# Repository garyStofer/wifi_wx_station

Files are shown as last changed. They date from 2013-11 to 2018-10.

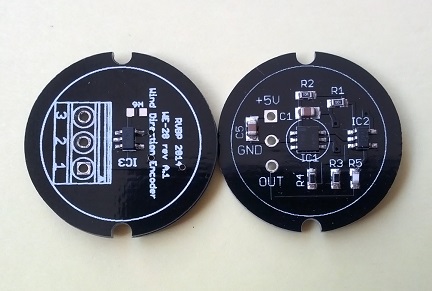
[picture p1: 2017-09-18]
Hardware/Wifi_WX_Station/Documents/WE28_PCB_small.jpg

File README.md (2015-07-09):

# wifi_wx_station
This project is for a full featured, self contained weather station that connects via WiFi to home network and uploads periodic readings
to various cloud based weather data ingestion service, such as Weather Underground, CWOP, WOW, etc.

The hardware is based on a Microchip controller with an attached Microchip WiFi module. 
The various sensors arepart of the project with the air data sensors (baro/temp/hyg) based onn i2C devices. 
The wind sensord are of unique solid state design ( optical, magnetic) and proide a high degree of precision, fidelity and reliability.

More information at http://wws.us.to

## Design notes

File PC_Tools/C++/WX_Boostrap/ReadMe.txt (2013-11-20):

Extract the files in this zip file to a location on your harddrive and make a shortcut to WX_Bootstrat.exe 
that you can put on the desktop for eaxmple.

The file TCPIP_Discovery.jar is a java program that displays the Netbioas name and the IP address of a WX_station
board after it's connected to the network. The Java Run time must be installed on the computer to run it.

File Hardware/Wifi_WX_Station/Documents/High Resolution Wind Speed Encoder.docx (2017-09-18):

# High Resolution Wind Speed Encoder

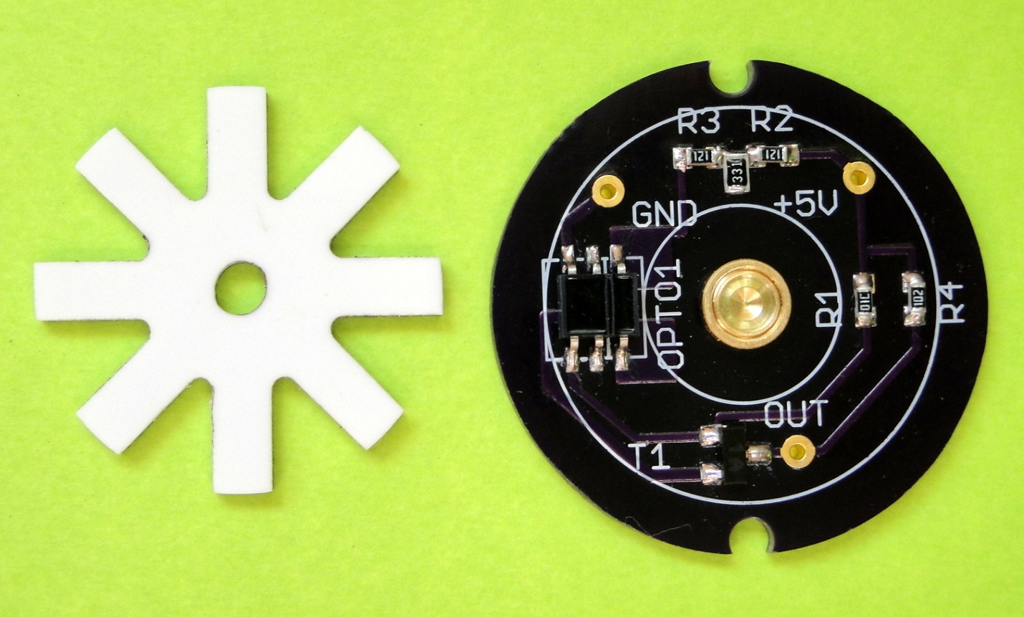
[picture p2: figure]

# Description

Based on a reflective optical interrupt device the sensors provides an eight fold increase in resolution for wind speed measurements compared to a basic reed switch device. This allows for a reduced measure interval, thus enabling the capture of short period wind gusts and airspeeds down to 0.5 Mph. The sensor asserts no drag on the anemometer cups, which, coupled with the sapphire bearing, makes for a virtually drag-free setup.

# Applications

- High definition/resolution wind speed monitoring & recording
- Capturing of micro gusts
- Capturing of very low wind-speeds
- DIY and custom weather stations

# Features

- Solid state
- Drag free
- Eight times the resolution compared to standard sensors
- Interfaces direct to microcontroller inputs
- No false readings due to reed switch bounce or magnetic fatigue
- Built in Hysteresis

# Electrical specifications

- Input voltage nominal 5V, maximum 5.5V
- Do not short output to ground
- Do not short output to +5V
- Required measure input impedance > 1K
- Current consumption 20 to 27mA @5V

Name | Symbol on PCB | Description | Condition
Ground | GND | Ground reference | --
Power | +5V | Regulated power input | 5V +/- 5% , less than 50mv noise
Output Signal | OUT | 8 pulses per revolution | Low <0.15V, | High <3.5>3V

# The device can sink and source 1.5ma. It is intended to be connected to a high impedance micro processor input through a series resistor and transorb or shottky diode for transient protection of the input on long cable runs.

# Mechanical specifications

- PCB dimension: Rround, 1” diameter
- Sensor to rotor distance 1.5mm +/- 10%

+5V regulated supply

System Ground

Output Signal

Note on revolution to wind speed calculations

When used with Inspeeds anemometer cups, 60 revolutions per minute equals 2.5MPH

When used with Davis Instruments cups , 60 RPM equals 2.25 MPH

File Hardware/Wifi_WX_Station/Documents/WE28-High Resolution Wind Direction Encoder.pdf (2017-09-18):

# High Resolution Wind Direction Encoder

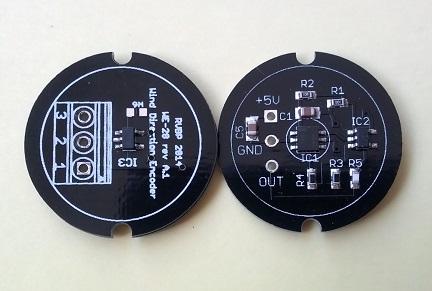
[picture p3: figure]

### Description

Based on a quad Hall- effect sensor the device reads the direction of a magnetic field provided by a small diametrically polarized magnet rotating above it. The device provides a linear voltage between 0 and 3V or 4.8V, coinciding with the absolute angle of the magnet and has no dead spot in the full 360 degree swing. The sensor, being completely solid state asserts no drag on the vane and has no mechanical parts to wear out.

### Applications

High definition/resolution wind direction monitoring & recording DIY and custom weather stations

### Features

Drag free
Maintenance free, solid state
No blind spots in full circle
No false readings due to partially worn potentiometer.

Interfaces direct to microcontroller ADC inputs

### Electrical specifications

Input voltage nominal 5V, maximum 5.5V Desired ADC input impedance > 100K DC output impedance ~ 10K
Current consumption 18 mA @5V Resolution +/- 0.5 deg

### Connections

Name | Symbol on PCB | Description | Condition
Ground | GND | Ground reference | --
Power | +5V | Regulated power input | 5V +/- 5% , less than 50mv noise
Output Signal | OUT | ~0V to ~3.3V coinciding with angle 0-360 degree | Low <0.1V, | High <3.3>3V

### Mechanical specifications

PCB dimension: Rround, 1” diameter Sensor to magnet distance 1.5mm +/- 10%

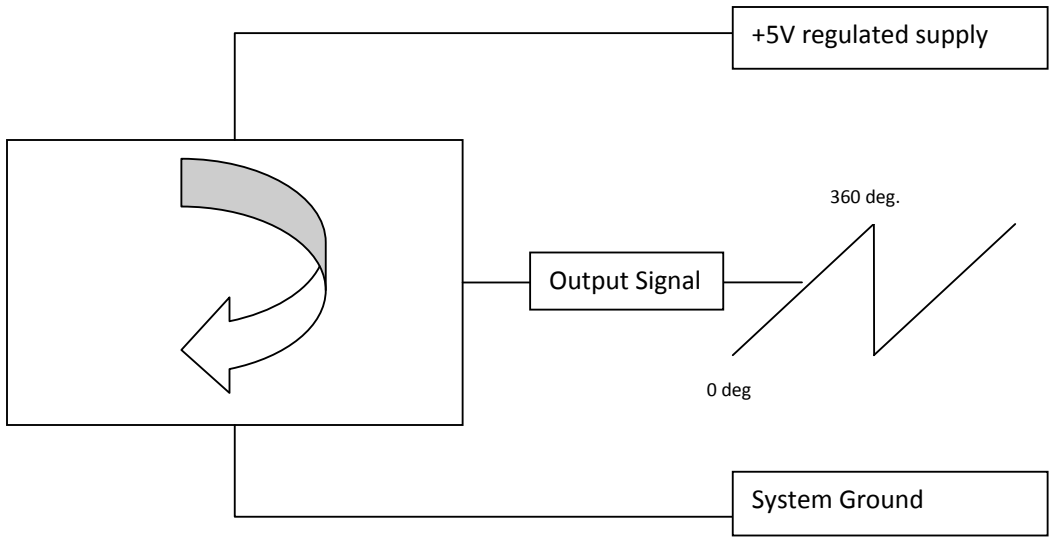
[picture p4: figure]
+5V regulated supply; System Ground; Output Signal; 0 deg; 360 deg.

See schematic for 3V v.s. 4.8V output build options.

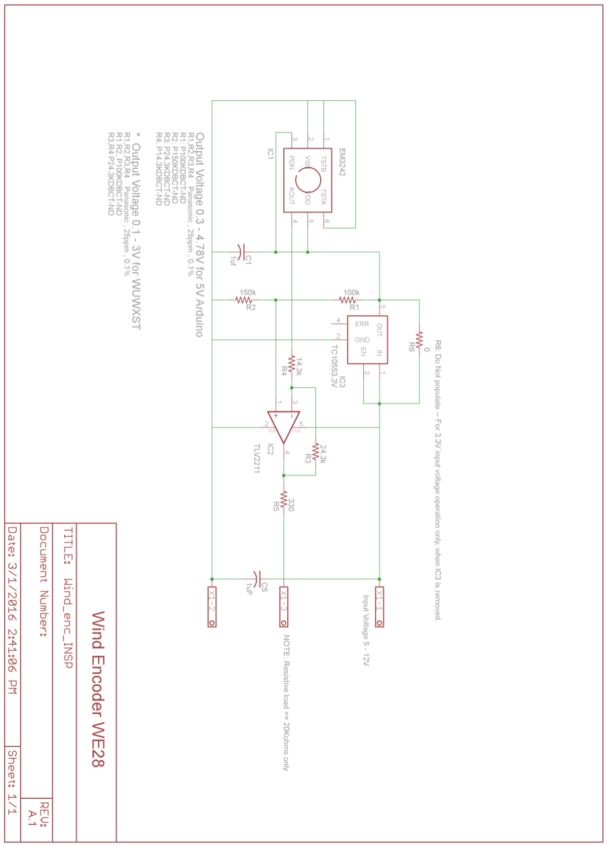
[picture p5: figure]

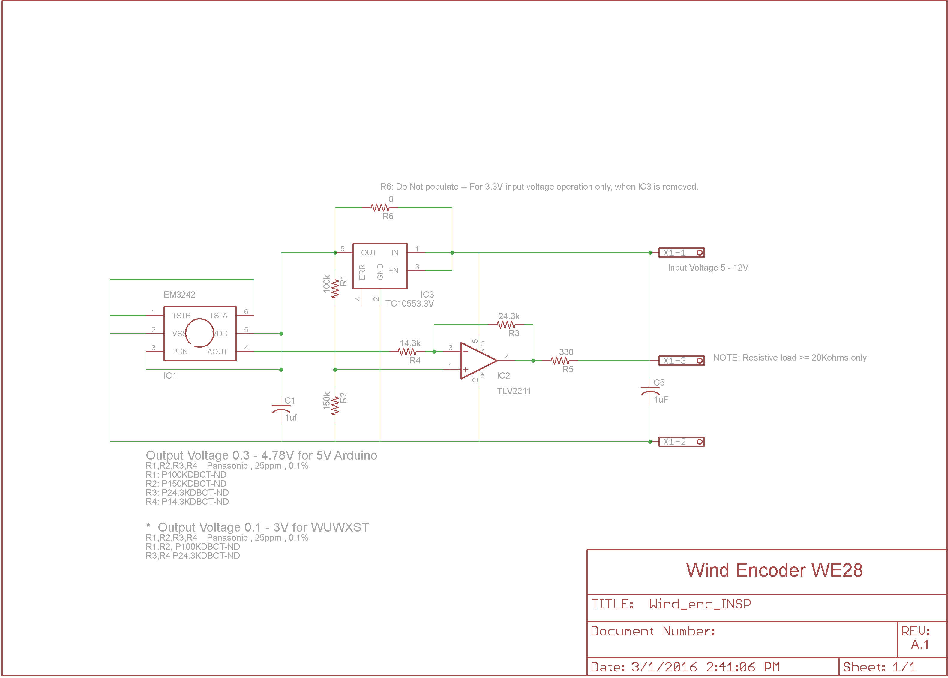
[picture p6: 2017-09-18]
Hardware/Wifi_WX_Station/WindDir_WE28_A.1/WE28_A1.png

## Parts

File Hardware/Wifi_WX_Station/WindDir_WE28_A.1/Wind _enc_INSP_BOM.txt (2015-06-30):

BOM for WE28-A1

OP-Amp 	TLV2211		DigiKey 	296-10501-1-ND	 
Encoder EM3242		Digikey  	974-1044-1-ND	 
VR 	TC10553.3V	DigiKey		TC10553.3VCT713CT-ND			 
R1 	100K 0.5% 25ppm 	 
R2	150K 0.1% 25ppm	 
R3	24.3k 0.1% 25ppm	 
R4 	14.3k 0.5% 25ppm	 
R5	330O 2%			 
C1,C2	1 uf/ 16V  			311-1457-1-ND

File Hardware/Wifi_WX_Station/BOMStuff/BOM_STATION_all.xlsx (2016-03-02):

Station Base Board PCB
Qty | Description | Value | Package | Parts | PN_ DigiKey | PN Mouser | Alt Vendor | Alt Vendor PN | Alt vendor Price | X10 | X100 | extended cost per one | extened +taxes
13 | Capacitor | 0.1uF | C0805 | C2, C3,C4,C5,C6,C8,C11,C13,C16,C18,C19,C20,C21 | 478-1395-1-ND | 80-C0805C104K5R |  |  |  | $0.48 | $2.30 | $0.62
1 | Capacitor, Polarized | 220uF/6V | SMC_D | C7 |  | 581-TPSC227K006Y0125 |  |  |  | $10.80 | $82.00 | $1.08
2 | Capacitor, Polarized | 22uF/10V | SMC_B | C1,C12 | 493-2357-1-ND | 74-TP3B226M010C1900A |  |  |  | $3.10 | $14.00 | $0.62
2 | Capacitor | 2.2uF | C0805 | C9, C10 | 445-3459-1-ND | 963-TMK212B7225KG-TR |  |  |  | $1.81 | $8.30 | $0.36
2 | Capacitor | 22p | C0603 | C14, C15 | 445-1273-1-ND | 77-VJ0603A220JXACBC (http://www.mouser.com/ProductDetail/Vishay-Vitramon/VJ0603A220JXACW1BC/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) |  |  |  | $0.30 |  | $0.06
1 | Resistor | 14K | R0603 | R8 | 311-14.0KHRCT-ND |  |  |  |  | $0.14 | $0.63 | $0.01
3 | Resistor | 100K | R0603 | R7,R19,R20 |  | 660-RK73H1JTTD1003F |  |  |  | $0.14 | $0.70 | $0.04
2 | Resistor | 1K | R0603 | R16, R17 | 311-1.0KGRCT-ND | 667-ERJ-3EKF1001V |  |  |  | $0.10 | $0.48 | $0.02
3 | Resistor | 10K | R0603 | R3,R4,R11, | 311-10.0KHRCT-ND | 667-ERJ-3EKF1002V |  |  |  | $0.14 | $0.63 | $0.04
2 | Resistor | 120o | R0603 | R1, R2, | 311-120GRCT-ND |  |  |  |  | $0.10 | $0.48 | $0.02
1 | Resistor | 8.2K | R0603 | R5 | 311-8.2KGRDKR-ND |  |  |  |  | $0.10 | $0.48 | $0.01
5 | Resistor | 4.7K | R0603 | R12,R14,R15,R23,R24 | 311-4.7KGRDKR-ND |  |  |  |  | $0.10 | $0.48 | $0.05
1 | Resistor | 470O | R0603 | R18 | 311-470GRCT-ND |  |  |  |  | $0.10 | $0.48 | $0.01
1 | Resistor | 2.2K | R0603 | R13 | 311-2.2KGRDKR-ND |  |  |  |  | $0.10 |  | $0.01
4 | Resistor | 26.1K | R0603 | R9,R10,R21,R22 | 311-26.1KHRCT-ND |  |  |  |  | $0.14 | $0.63 | $0.06
1 | VOLTAGE REGULATOR, LDO 3.3v | LD29150DT33R | DPACK | IC1 | 497-1496-1-ND | 511-LD29150DT33R |  |  |  | $9.50 | $82.00 | $0.95
1 | CRYSTAL | 32Khz | SMD-Can | Q1 | 300-8340-1-ND | 959-WX26-32.768K |  |  |  | $4.80 | $32.00 | $0.48
1 | Schottky Diode | B140 | SMB | D1 | 641-1111-1-ND | 625-SS14-E3 |  |  |  | $1.00 | $6.10 | $0.10
1 | Shottky Diode | MBR0520 | SOD123 | D2 | MBR0520TPMSCT-ND |  |  |  |  | $3.00 |  | $0.30
1 | MINI USB-B Conector | MINI-USB-32005-301 | 32005-301 | USB | ED2992CT-ND | 649-10033526-N3212LF |  |  |  | $4.83 | $42.20 | $0.48
1 | USB /UART | CP2104-GM | QFN24_4X4 | U1 | 336-2008-5-ND | 634-CP2104-F03-GM |  |  |  | $14.30 | $133.00 | $1.43
2 | Molex KK 6373 header with lock | CONN HEADER 3POS .100 VERT TIN | 0.1x3 Vert | FAN, SUN,+5V | WM4201-ND | 538-22-23-2031 |  |  |  | $1.53 | $12.20 | $0.31
0 | Male header 1x3 | 2 Not Loaded | 0.1x3 | UART1, I2C1 | 609-3464-ND |  |  |  |  | $1.46 |  | $0.00
0 | Male header 1x6 | 1 Not Loaded | 0.1x6 | JPROG | 609-3256-ND |  |  |  |  | $3.05 |  | $0.00
0 | Male header 1x10 | 3 Not Loaded | 0.1x10 | SV1,SV2,SV3 | 609-3279-ND |  |  |  |  | $4.61 |  | $0.00
0 | Male header 1x5 | 1 Not Loaded | 0.1x5 | ANA | 609-3462-ND |  |  |  |  | $1.92 |  | $0.00
1 | RJ45 Jack LP-Vertical Molex | RJ45-8VERT | RJ45_VERT | J1 | AE10396-ND | 538-42878-1001 |  |  |  | $6.70 | $64.70 | $0.67
1 | RJ11 Jack LP-Vertical Molex | RJ11-6VERT | RJ11-6VERT | J5 /BaroHyg |  | 538-42878-6264 |  |  |  | $9.90 | $73.70 | $0.99
1 | PIC MCU 128K | PIC24FJ128GA008 | TQFP80-12X12 | U3 | PIC24FJ128GA008-I/PT-ND5.2 | 579-24FJ128GA008IPT |  |  |  | $37.00 | $307.00 | $3.70
0 | PIC MCU 256K/ Alternate | PIC24FJ256GA108 | TQFP80-12X12 |  | PIC24FJ256GA108-I/PT-ND7.42 |  |  |  |  | $51.80 |  | $0.00
1 | EEprom 512kbit | 25LC512 | SOIC8 | U2 | 25LC512-I/SN-ND | 579-25LC512-I/SN |  |  |  | $17.00 | $157.00 | $1.70
3 | Tactile Switch | SWITCH-MOMENTARY-2SMD |  | S1, S2, Reset | P12955SCT-ND | 667-EVQ-Q2P03W |  |  |  | $2.73 | $20.40 | $0.82
1 | LED | ambr | CHIP-LED0603 | L2 | 475-2558-1-ND | 859-LTST-C190KFKT |  |  |  | $0.78 |  | $0.08
1 | LED | grn | CHIP-LED0603 | L1 | 475-1409-1-ND | 859-LTST-C190KGKT |  |  |  | $0.74 |  | $0.07
1 | LED | red | CHIP-LED0603 | L3 | 475-2512-1-ND | 859-LTST-C190KRKT |  |  |  | $0.78 |  | $0.08
1 | PCB, Elcrow |  |  |  |  | Elcrow 10 PCB order 5x10 |  |  |  | $20.00 |  | $2.00
 |  |  |  |  |  |  |  |  |  |  |  | $17.18 | $18.72
WiFi Interface Module & PCB
Qty | Description | Value | Package | Parts
2 | Capacitor | 0.1uF | C0805 | C1, C2 | 478-1395-1-ND |  |  |  |  | $0.48 | $2.20 | $0.10
1 | Resistor | 10K | R0603 | R2 | 311-10.0KHRCT-ND |  |  |  |  | $0.10 | $0.48 | $0.01
1 | Resistor | 4.7K | R0603 | R1 | 311-4.70KHRCT-ND |  |  |  |  | $0.10 | $0.48 | $0.01
1 | Capacitor Polarized | 4.7uF | R/2012-12R | C3 | 399-3696-1-ND | 80-T491A475K010 |  |  |  | $2.95 | $25.50 | $0.30
1 | Male Header 2x5 | M05X2 | 2X5-RA-HEADER | JP1 | 609-3410-ND |  |  |  |  | $3.56 |  | $0.36
1 | Mirochip/ZeroG Wifi module | MRF24WG0MA | MRF24WG | M1 | MRF24WG0MB/RM-ND | digitalrepair@hotmail.com<digitalrepair@hotmail.com>; | e-bay |  | $10.00 | $210.00 |  | $21.00
1 | PCB. Elcrow |  |  |  |  | Elcrow 10 PCB order 5x5 |  |  |  | $16.00 |  | $1.60
 |  |  |  |  |  |  |  |  |  |  |  | $23.37 | $25.47
Power feed & Sun, Rain input PCB
Qty | Description | Value | Package | Parts
2 | Molex KK 6373 header with lock | CONN HEADER 3POS .100 VERT TIN |  | Rain, Sun | WM4201-ND |  |  |  |  | $2.80 |  | $0.56
1 | MINI USB-B Conector | MINI-USB-32005-301 | 32005-301 | USB | ED2992CT-ND | 649-10033526-N3212LF |  |  |  | $4.83 |  | $0.48
2 | RJ45 Jack | RJ45-8VERT | RJ45_VERT | J1, J2 | AE10396-ND | 538-42878-1001 |  |  |  | $6.67 |  | $1.33
1 | PCB, ELCROW |  |  |  |  | Elcrow 10 PCB order 5x5 |  |  |  | $16.00 |  | $1.60
 |  |  |  |  |  |  |  |  |  |  |  | $3.98 | $4.33
Wind tree distributor PCB
Qty | Description | Value | Package | Parts
1 | RJ45 Jack | RJ45-8VERT | RJ45_VERT | J1 | AE10396-ND | 538-42410-8314 |  |  |  | $7.47 |  | $0.75
1 | PCB. ELcrow | Gold Phoenix 100 @ $1.10 |  |  |  | Elcrow 10 PCB order 5x5 |  |  |  | $16.00 |  | $1.60
 |  |  |  |  |  |  |  |  |  |  |  | $2.35 | $2.56
Wind VANE
1 | Wind vane | DAVIS WIND VANE 7904 |  | http://www.ambientweather.com/dain79wivafo.html |  |  |  |  |  | $150.00 |  | $15.00
1 | Magnet diametrically polarized |  |  |  |  |  |  |  |  | $5.00 |  | $0.50
2 | Bearings |  |  |  |  |  |  |  |  | $25.00 |  | $5.00
1 | Axcel |  |  |  |  |  |  |  |  | $40.00 |  | $4.00
2 | C-clips 1/4 |  |  |  |  |  |  |  |  | $10.00 |  | $2.00
1 | Ft Cable 3-pole |  |  |  |  |  |  |  |  | $50.00 |  | $5.00
1 | Housing |  |  |  |  |  |  |  |  | $75.00 | $400.00 | $7.50
 |  |  |  |  |  |  |  |  |  |  |  | $39.00 | $42.51
Wind Direction Sensor PCB & magnet
1 | IC | AS5030 | TSSOP 16 |  | AS5030-ATSTCT-ND | 985-AS5030-ATSU @4.86x10 | Future |  | $2.89 | $48.60 |  | $4.86
3 | Capacitor | 1uF | C0805K | C1, C2, C5 | 490-5320-1-ND |  |  |  |  | $3.05 |  | $0.91
1 | Pol Capacitor | 220uF/6.3V | SMC_D | C6 |  | 581-TPSC227K006Y0125 |  |  |  | $10.80 |  | $1.08
1 | Resistor | 8.2k | R0603 | R6 | 311-8.2KGRDKR-ND |  |  |  |  | $0.10 |  | $0.01
1 | Resistor | 26.2K | R0603 | R2 | 311-26.1KHRCT-ND |  |  |  |  | $0.10 |  | $0.01
1 | Diametrically magnetized magnet |  |  |  | K&J magnets |  |  |  |  | $5.00 |  | $0.50
1 | Resistor | 6.8K | R0603 | R1 | 311-6.80KHRCT-ND |  |  |  |  | $0.10 | $0.63 | $0.01
1 | PCB, Elcrow |  |  |  |  | Elcrow 10 PCB order 5x5 |  |  |  | $16.60 |  | $1.66
 |  |  |  |  |  |  |  |  |  |  |  | $9.04 | $9.86
Anemometer
1 | Anemometer | DAVIS VANTAGE VUE WIND CUPS 7342.178 |  | http://www.ambientweather.com/da7342178.html |  |  |  |  |  | $150.00 |  | $15.00
1 | Housing 2parts |  |  |  |  |  |  |  |  | $60.00 | $400.00 | $6.00
2 | Bearings |  |  |  |  |  |  |  |  | $25.00 |  | $5.00
1 | Axcel |  |  |  |  |  |  |  |  | $40.00 |  | $4.00
2 | C-clips 1/4 |  |  |  |  |  |  |  |  | $10.00 |  | $2.00
1 | Ft Cable 3-pole |  |  |  |  |  |  |  |  | $50.00 |  | $5.00
 |  |  |  |  |  |  |  |  |  |  |  | $37.00 | $40.33
Windspeed sensor PCB and Rotor
1 | Reflective opto interrupter | OSRAM SFH9201 |  | OPTO1 | 475-2658-1-ND | 720-SFH9206 |  |  |  | $7.42 | $67.20 | $0.74
1 | Transistor NPN | MMBT3904 |  | T1 | MMBT3904TPMSCT-ND |  |  |  |  | $2.07 |  | $0.21
2 | Resistor | 120 O | R0603 | R1,R2 | 311-120GRCT-ND | 71-CRCW0603-120-E3 |  |  |  | $0.10 | $0.48 | $0.02
1 | Resistor | 10K | R0603 | R3 | 311-10.0KHRCT-ND | 71-CRCW0603-10K-E3 |  |  |  | $0.14 | $0.63 | $0.01
1 | Resistor | 330 O | R0603 | R5 |  | 71-CRCW0603-330-E3 |  |  |  | $0.10 |  | $0.01
1 | Resistor | 1K | R0603 | R4 | 311-1.0KHRCT-ND | 71-CRCW0603-1.0K-E3 |  |  |  | $0.14 | $0.63 | $0.01
1 | PCB |  |  |  |  | Elcrow 10 PCB order 5x5 |  |  |  | $16.60 | $0.06 | $1.66
1 | Rotor |  |  |  |  |  |  |  |  | $40.00 |  | $4.00
 |  |  |  |  |  |  |  |  |  |  |  | $6.67 | $7.27
Barometer & HoneyWell Hygrometer PCB
Qty | Description |  | Package | Parts
2 | Resistor | 470O | R0603 | R1,R2 | 311-470GRCT-ND | 71-CRCW0603-470-E3 |  |  |  | $0.10 | $0.48 | $0.02
2 | Capacitor | 0.1uF | C0805 | C1, C4 | 478-1395-1-ND | 80-C0805C104K5R |  |  |  | $0.48 | $2.20 | $0.10
1 | Capacitor, Polarized | 22uF/10V | SMC_B | C3 | 493-2357-1-ND |  |  |  |  | $4.69 |  | $0.47
1 | Sensor Hygrometer | HIH_6131,hih7131 | SOIC-8 | U1 |  | 785-HIH-6131-021-001 |  |  |  | $149.10 |  | $14.91 |  | digikey hih7131 : $15.67 | allied hih6131 $13.50
1 | Sensor Barometer /Temperatur | BMP085 | LCC8 | U2 | 828-1005-1-ND |  | China |  | $2.50 | $60.52 |  | $6.05
1 | RJ12 LP horizontal | RJ12-6pole Hor |  |  |  | 538-43249-6101 |  |  |  | $10.10 |  | $1.01
1 | PCB |  |  |  |  | Elcrow 10 PCB order 5x5 |  |  |  | $16.60 |  | $1.66
 |  |  |  |  |  |  |  |  |  |  |  | $24.22 | $26.40
Barometer & Silabs Hygrometer PCB
Qty | Description |  | Package | Parts
2 | Resistor | 470O | R0603 | R1,R2 | 311-470GRCT-ND | 71-CRCW0603-470-E3 |  |  |  | $0.10 | $0.48 | $0.02
2 | Capacitor | 0.1uF | C0805 | C1, C4 | 478-1395-1-ND | 80-C0805C104K5R |  |  |  | $0.48 | $2.20 | $0.10
1 | Capacitor, Polarized | 22uF/10V | SMC_B | C3 | 493-2357-1-ND | 80-T491A226K019 |  |  |  | $4.69 |  | $0.47
1 | Sensor Barometer /Temperatur | BMP085 | LCC8 | U2 | 828-1005-1-ND |  | China |  | $2.50 | $60.52 |  | $6.05
1 | Si7021-A10-GM1 | Silabs 2% with filter |  |  |  | 634-SI7021-A-GM1 $4.27 |  |  |  | $42.70 | $395.00 | $4.27
1 | RJ12 LP horizontal | RJ12-6pole Hor |  |  |  | 538-43249-6101 |  |  |  | $10.10 |  | $1.01
1 | PCB |  |  |  |  | Elcrow 10 PCB order 5x5 |  |  |  | $16.00 |  | $1.60
 |  |  |  |  |  |  |  |  |  |  |  | $13.52 | $14.73
Solar Sensor
1 | Solar Cell | CPC1822 | SOIC-8 |  | CLA289-ND |  |  |  |  | $12.40 | $98.00 | $1.24
1 | OP-amp | MAX4330 | SOT23-5 |  | MAX4330EUK+TCT-ND |  |  |  |  | $32.20 | $213.00 | $3.22
2 | Capacitor | 0.1uF | C0805 | C1, C2 | 478-1395-1-ND |  |  |  |  | $0.48 | $2.20 | $0.10
1 | Resistor | 47K |  | R1 | 311-47.0KHRCT-ND |  |  |  |  | $0.14 | $0.63 | $0.01
1 | Molex KK series connector housing | CONN HOUS 3POS .100 W/RAMP/RIB |  |  | WM2003-ND |  |  |  |  | $1.74 | $10.73 | $0.17
3 | Crimp terminal for Molex KK connector |  |  |  | WM1114CT-ND | 538-08-50-0114 |  |  |  | $0.50 | $4.66 | $0.15
1 | PCB | Gold Phoenix 100 @ $1.10 |  |  |  |  |  |  |  | $10.00 |  | $1.00
 |  |  |  |  |  |  |  |  |  |  |  | $5.89 | $6.42
Baro_hyg_temp Cable
2 | RJ12 / Cat3 modular Plugs |  |  |  |  | 154-7623-6 |  |  |  | $2.40 | $18.00 | $0.48
1 | RJ12 6 pole cable |  |  |  |  |  |  |  |  | $10.00 |  | $1.00
 |  |  |  |  |  |  |  |  |  |  |  | $1.48 | $1.61
Post Enclosure , cabling, power supply
1 | Severe Weather Post SLV COMP | Item # 160835 |  |  | Lowes |  |  |  |  | $100.00 |  | $10.00
1 | Severe Weather Kove Base | Item #7067 |  |  | Lowes |  |  |  |  | $70.00 |  | $7.00
1 | Severe Weather Post Cap Bevel | Item #100437 |  |  | Lowes |  |  |  |  | $50.00 |  | $5.00
1 | FAN 12V/5V | FAN 12V/5V, 92mmx92mm |  |  | 259-1468-ND |  |  |  |  | $24.64 |  | $2.46
2 | Crimp terminal for Molex KK connector |  |  |  | WM1114CT-ND |  |  |  |  | $0.50 |  | $0.10
1 | Molex KK series connector housing | CONN HOUS 3POS .100 W/RAMP/RIB |  |  | WM2001-ND |  |  |  |  | $1.74 |  | $0.17
2 | Mounting bracket for base pcb |  |  |  |  |  |  |  |  | $10.00 |  | $2.00
1 | USB Powersupply 5V/1A USB-Mini-B |  |  |  |  |  |  |  |  | $50.00 |  | $5.00
1 | 25 feet CAT5 Ethernet cable 22ga |  |  |  | Frys |  |  |  |  | $120.00 |  | $12.00
1 | 14 feet CAT5 Ethernet cable 22ga |  |  |  | Frys |  |  |  |  | $50.00 |  | $5.00
 |  |  |  |  |  |  |  |  |  |  |  | $0.00
No labor | Cost for main brd, Wifi, & baro_hyg sensor SI | $60.54 | +plus $14 for HWELL hyg |  | No labor, calculated from X10 order quantities |  | Parts Shipping cost + $2
No labor | Cost for Winspeed sensor board & Rotor | $7.27 |  |  | "
No labor | cost for Wind Direction sensord board & Magnet | $9.86 |  |  | "

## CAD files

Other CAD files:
Hardware/Wifi_WX_Station/Mechanical_CAD/PCB bracket.skp
Hardware/Wifi_WX_Station/Mechanical_CAD/WindSpeed2Housing top.skp
Hardware/Wifi_WX_Station/Mechanical_CAD/WindSpeedHousing2_bottom.skp
Hardware/Wifi_WX_Station/Mechanical_CAD/Wind_Speed_Axel.skp
Hardware/Wifi_WX_Station/Mechanical_CAD/Wind_Vane_Axel.skp
Hardware/Wifi_WX_Station/Mechanical_CAD/Wind_speed_rotor.skp
Hardware/Wifi_WX_Station/Mechanical_CAD/Wind_speed_rotor_cnc.skp

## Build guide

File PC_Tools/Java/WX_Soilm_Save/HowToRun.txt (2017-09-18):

First Install Java Runtime environment (JRE) on the computer. If it's a Windows XP computer you will get 
an notice that Java 8 is not actively supported any more. You can disregard the message and install it anyway. 

The application is WXSoilSave.jar and requires two command line arguments, one for the IP address the other
for the sample interval (optional, default 12 mins).

java -jar WXSoilSave.jar -ip 192.168.1.201 -i 12 

	Mandatory argument "-ip  xxx.xxx.xxx.xxx" defines the address of the WX station 
	Optional argument "-i nn" sets the interval in minutes for polling of that station.

The file "run.cmd" is a batch file that can be customized for your particular requirements. 
Make a copy each of this file and change the IP addresses to match the addresses from the stations
and run each copy.

The output data file will be stored in the local folder and named according to the IP address of the
station sampled. 

You can stop the program by switching to the terminal window and close it or issue a Ctrl-C.
The application also terminates if the station is off and it times-out on the read.

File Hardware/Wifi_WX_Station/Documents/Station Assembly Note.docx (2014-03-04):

## A few notes on assembly of the Weather Station

In random order:

Check out the Help and the Document section on http://WunderWeatherstation.wordpress.com for hookup and configuration procedures. You will have to download some PC tools to bootstrap the device onto your Wifi network.

The Air-Data sensor currently comes with a 2” ribbon cable and a 5 pin inline connector. If your installation requires a greater distance between the main PCB and the sensor you can extend the wire with a suitable cable up to 20 feet. The short connection is best used with a force aspirated enclosure where a fan constantly draws air through the enclosure. I will have a new version of sensor available soon which uses a modular connector and a FAX/Phone cable for more hookup options.

On the wind tree assembly it should be obvious how to put it together, but make sure that you glue the PVC parts together to make them water proof. Use a run of electrical tape to hold together and seal the joints between the black Inspeed housings and the white PVC parts .

For esthetics and protection from UV I usually paint the finished PVC parts .

If you don’t use the sun input on the round wind tree distribution pcb solder the holes shut.

The Distribution PCB in the bottom of the 1” coupling needs an O-ring to seal, make sure that when you glue this together that the PCB is held tight against the O-ring without it wiggling. You will need to hold the parts together for a minute or so while the glue sets.

Don’t glue the Wind tree to the 1” pipe, simply press on and use electrical tape to hold the joint together.

If you permanently mount the wind tree on a pipe longer than 3” drill one ½ hole near the top, so that air can circulate in the pipe to prevent condensation near the connector.

The calibration factor for the Inspeed anemometer cups is exactly 2.5. Make sure you re-enter this in the sensor configuration page after a reset. The Default 2.25 is for the Davis cups.

Use good CAT5 cable, soft and pliable. Outdoor quality is preferred. On the cheap stuff the outer shell can crack after only one year out in the sun. Then the rainwater can enter the cable and flood your base station PCB, and that’s ugly.

Make sure not to forget to set the station elevation in the Station Setup page even if you don’t report to weather underground. The elevation is needed to calculate the barometer reading. A reset is needed after the elevation has been changed.

Except for the solar sensor, the various gains and offsets should not need tweaking unless you have reliable data to justify it.

The solar sensor should be calibrated to read about 950 Watt/m2 facing directly at the sun. The current sensor while electrically linear is direction sensitive and needs some optical diffusion mechanism to be less affected by incidence angle.

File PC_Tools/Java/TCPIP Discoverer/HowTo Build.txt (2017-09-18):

This is a Java Netbeans project. 
Last built with NB 8.1 Using Java 6 source 

The executable .jar file is found in the dist folder.

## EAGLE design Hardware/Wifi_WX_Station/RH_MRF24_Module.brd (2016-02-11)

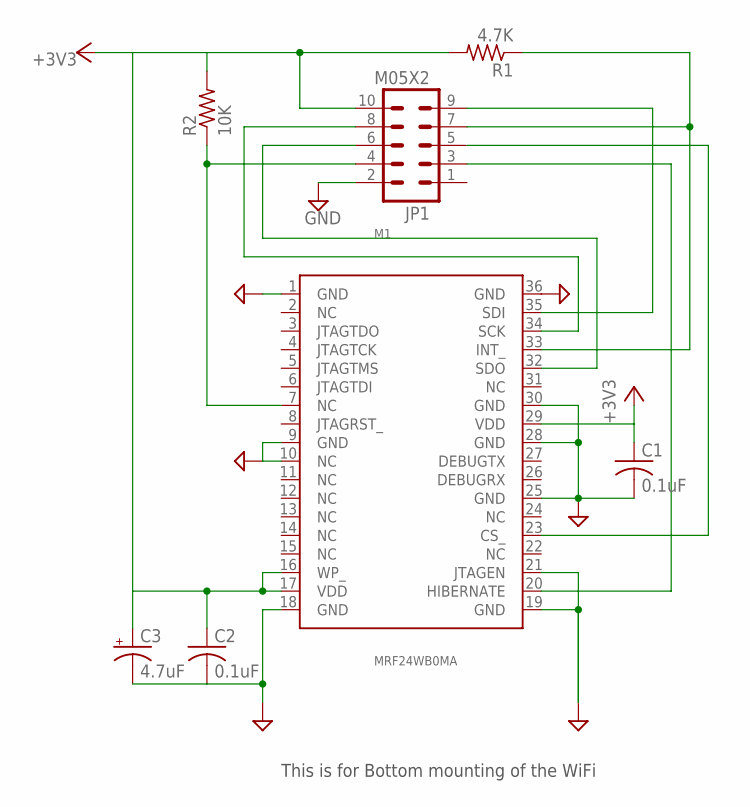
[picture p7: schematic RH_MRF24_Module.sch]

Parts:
C1, C2: 0.1uF; C0805
C3: 4.7uF; R/2012-12R
JP1: M05X2; 2X5-RA-HEADER
M1: MRF24WB0MA; MRF24W
R1: 4.7K; R0603
R2: 10K; R0603

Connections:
+3V3: C1.1, C2.1, C3.+, JP1.10, M1.16 (WP_), M1.17 (VDD), M1.29 (VDD), R1.2, R2.2
CS_: JP1.5, M1.23 (CS_)
GND: C1.2, C2.2, C3.-, JP1.2, M1.1 (GND), M1.9 (GND), M1.10 (NC), M1.18 (GND), M1.19 (GND), M1.21 (JTAGEN), M1.25 (GND), M1.28 (GND), M1.30 (GND), M1.36 (GND)
HIBER: JP1.3, M1.20 (HIBERNATE)
INT_: JP1.7, M1.33 (INT_), R1.1
RESET_: JP1.4, M1.7 (NC), R2.1
SCK: JP1.8, M1.34 (SCK)
SDI: JP1.9, M1.35 (SDI)
SDO: JP1.6, M1.32 (SDO)

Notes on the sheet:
This is for Bottom mounting of the WiFi

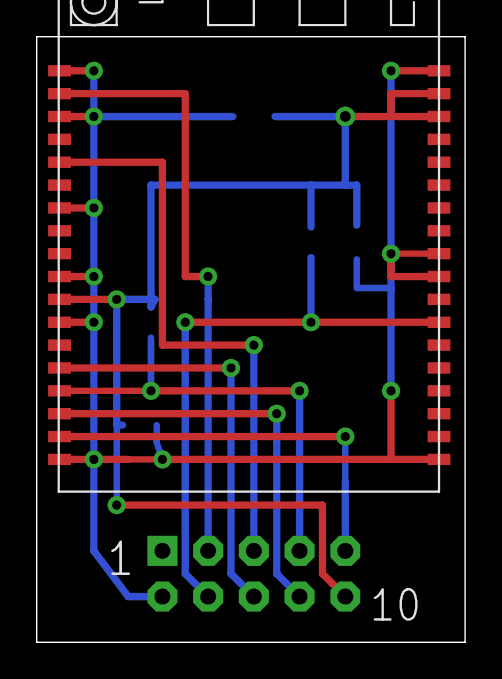
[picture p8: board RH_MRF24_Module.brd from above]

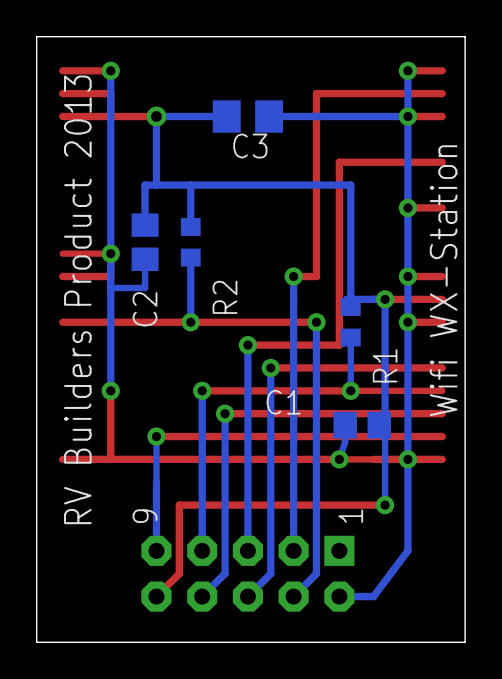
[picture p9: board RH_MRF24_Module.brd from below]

Board: 2 copper layers, 23.8 x 33.6 mm, 7 parts (6 on the bottom side), 9 nets.

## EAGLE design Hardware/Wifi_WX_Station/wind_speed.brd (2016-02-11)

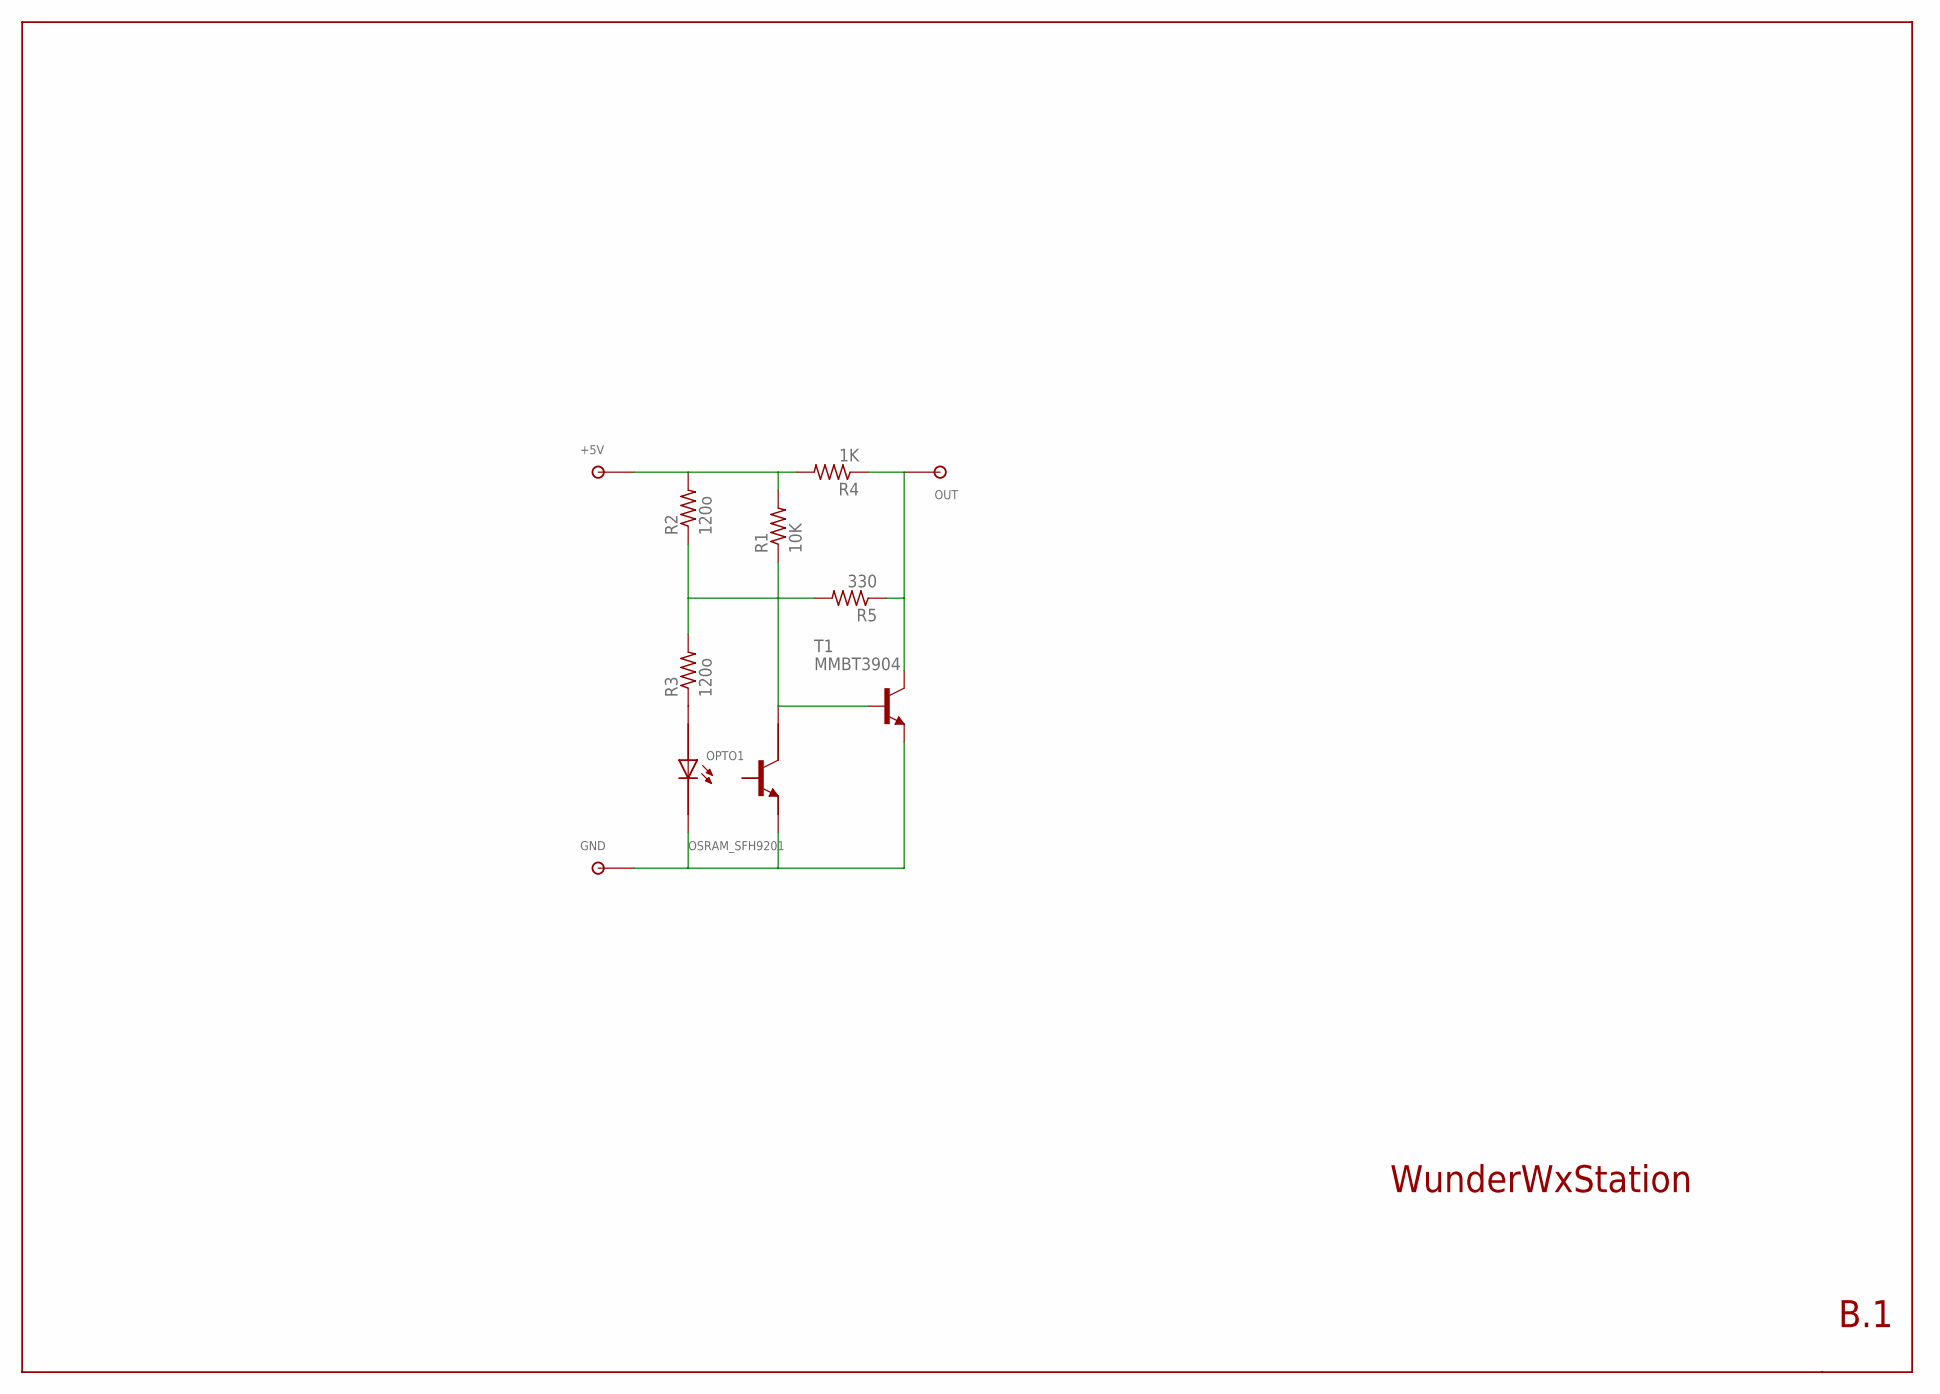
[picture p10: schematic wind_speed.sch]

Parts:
+5V: TPSOL; TP_SOL
GND: TPSOL; TP_SOL
OPTO1: OSRAM_SFH9201; OSRAM-6
OUT: TPSOL; TP_SOL
R1: 10K; R0603
R2, R3: 120o; R0603
R4: 1K; R0603
R5: 330; R0603
T1: MMBT3904; SOT23

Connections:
unnamed: OPTO1.P$4 (C), R1.1, T1.1 (B)
unnamed: GND.P$1, OPTO1.P$3 (E), OPTO1.P$6 (CATH), T1.2 (E)
unnamed: +5V.P$1, R1.2, R2.2, R4.2
unnamed: OUT.P$1, R4.1, R5.1, T1.3 (C)
unnamed: OPTO1.P$1 (AN), R3.1
unnamed: R2.1, R3.2, R5.2

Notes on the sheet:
WunderWxStation
B.1

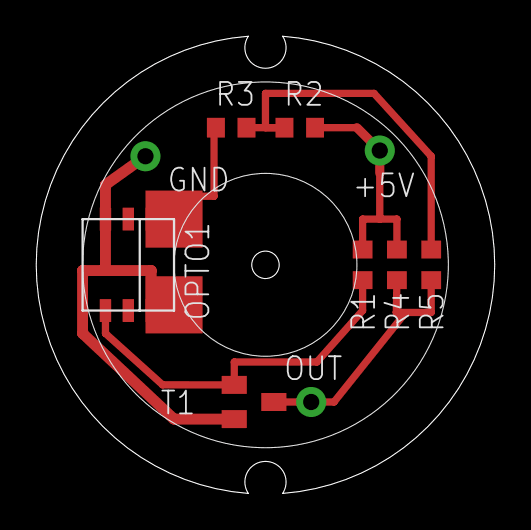
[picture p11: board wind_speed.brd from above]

Board: 2 copper layers, 25.5 x 25.4 mm, 10 parts (0 on the bottom side), 6 nets.

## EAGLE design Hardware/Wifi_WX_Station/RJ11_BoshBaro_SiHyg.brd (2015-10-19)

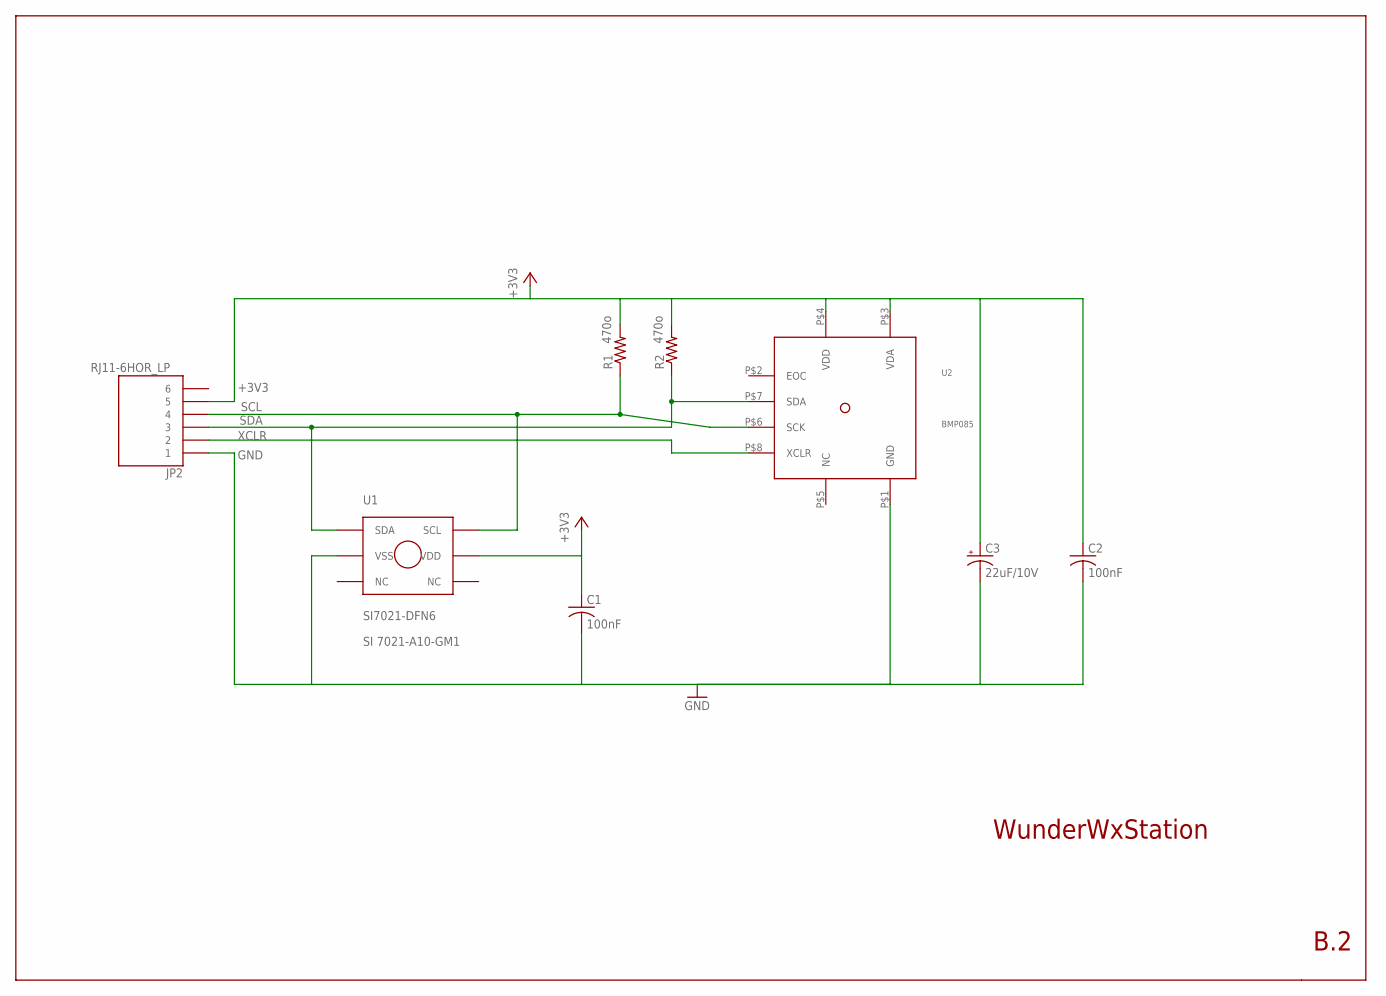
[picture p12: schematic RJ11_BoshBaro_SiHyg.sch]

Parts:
C1, C2: 100nF; C0805K
C3: 22uF/10V; SMC_B
JP2: RJ11-6HOR_LP; RJ11_HOR_LP
R1, R2: 470o; R0603
U1: SI7021-DFN6; DFN-6_SILABS
U2: BMP085; LCC8

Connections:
+3V3: C1.1, C2.1, C3.+, JP2.P$5 (5), R1.2, R2.2, U1.P$5 (VDD), U2.P$3 (VDA), U2.P$4 (VDD)
GND: C1.2, C2.2, C3.-, JP2.P$1 (1), U1.P$2 (VSS), U2.P$1 (GND)
SCL: JP2.P$4 (4), R1.1, U1.P$6 (SCL), U2.P$6 (SCK)
SDA: JP2.P$3 (3), R2.1, U1.P$1 (SDA), U2.P$7 (SDA)
XCLR: JP2.P$2 (2), U2.P$8 (XCLR)

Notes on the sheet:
WunderWxStation
B.2
SI 7021-A10-GM1

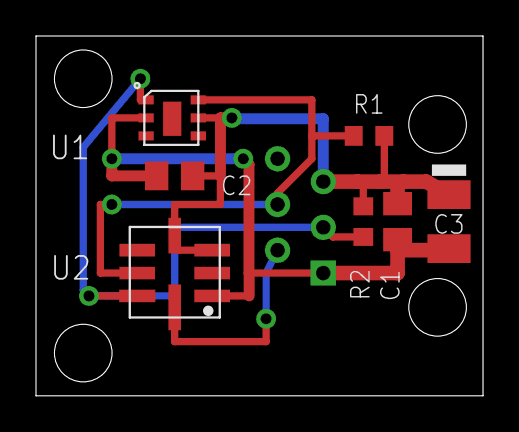
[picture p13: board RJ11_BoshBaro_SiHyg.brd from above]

Board: 2 copper layers, 24.8 x 20.0 mm, 8 parts (1 on the bottom side), 5 nets.

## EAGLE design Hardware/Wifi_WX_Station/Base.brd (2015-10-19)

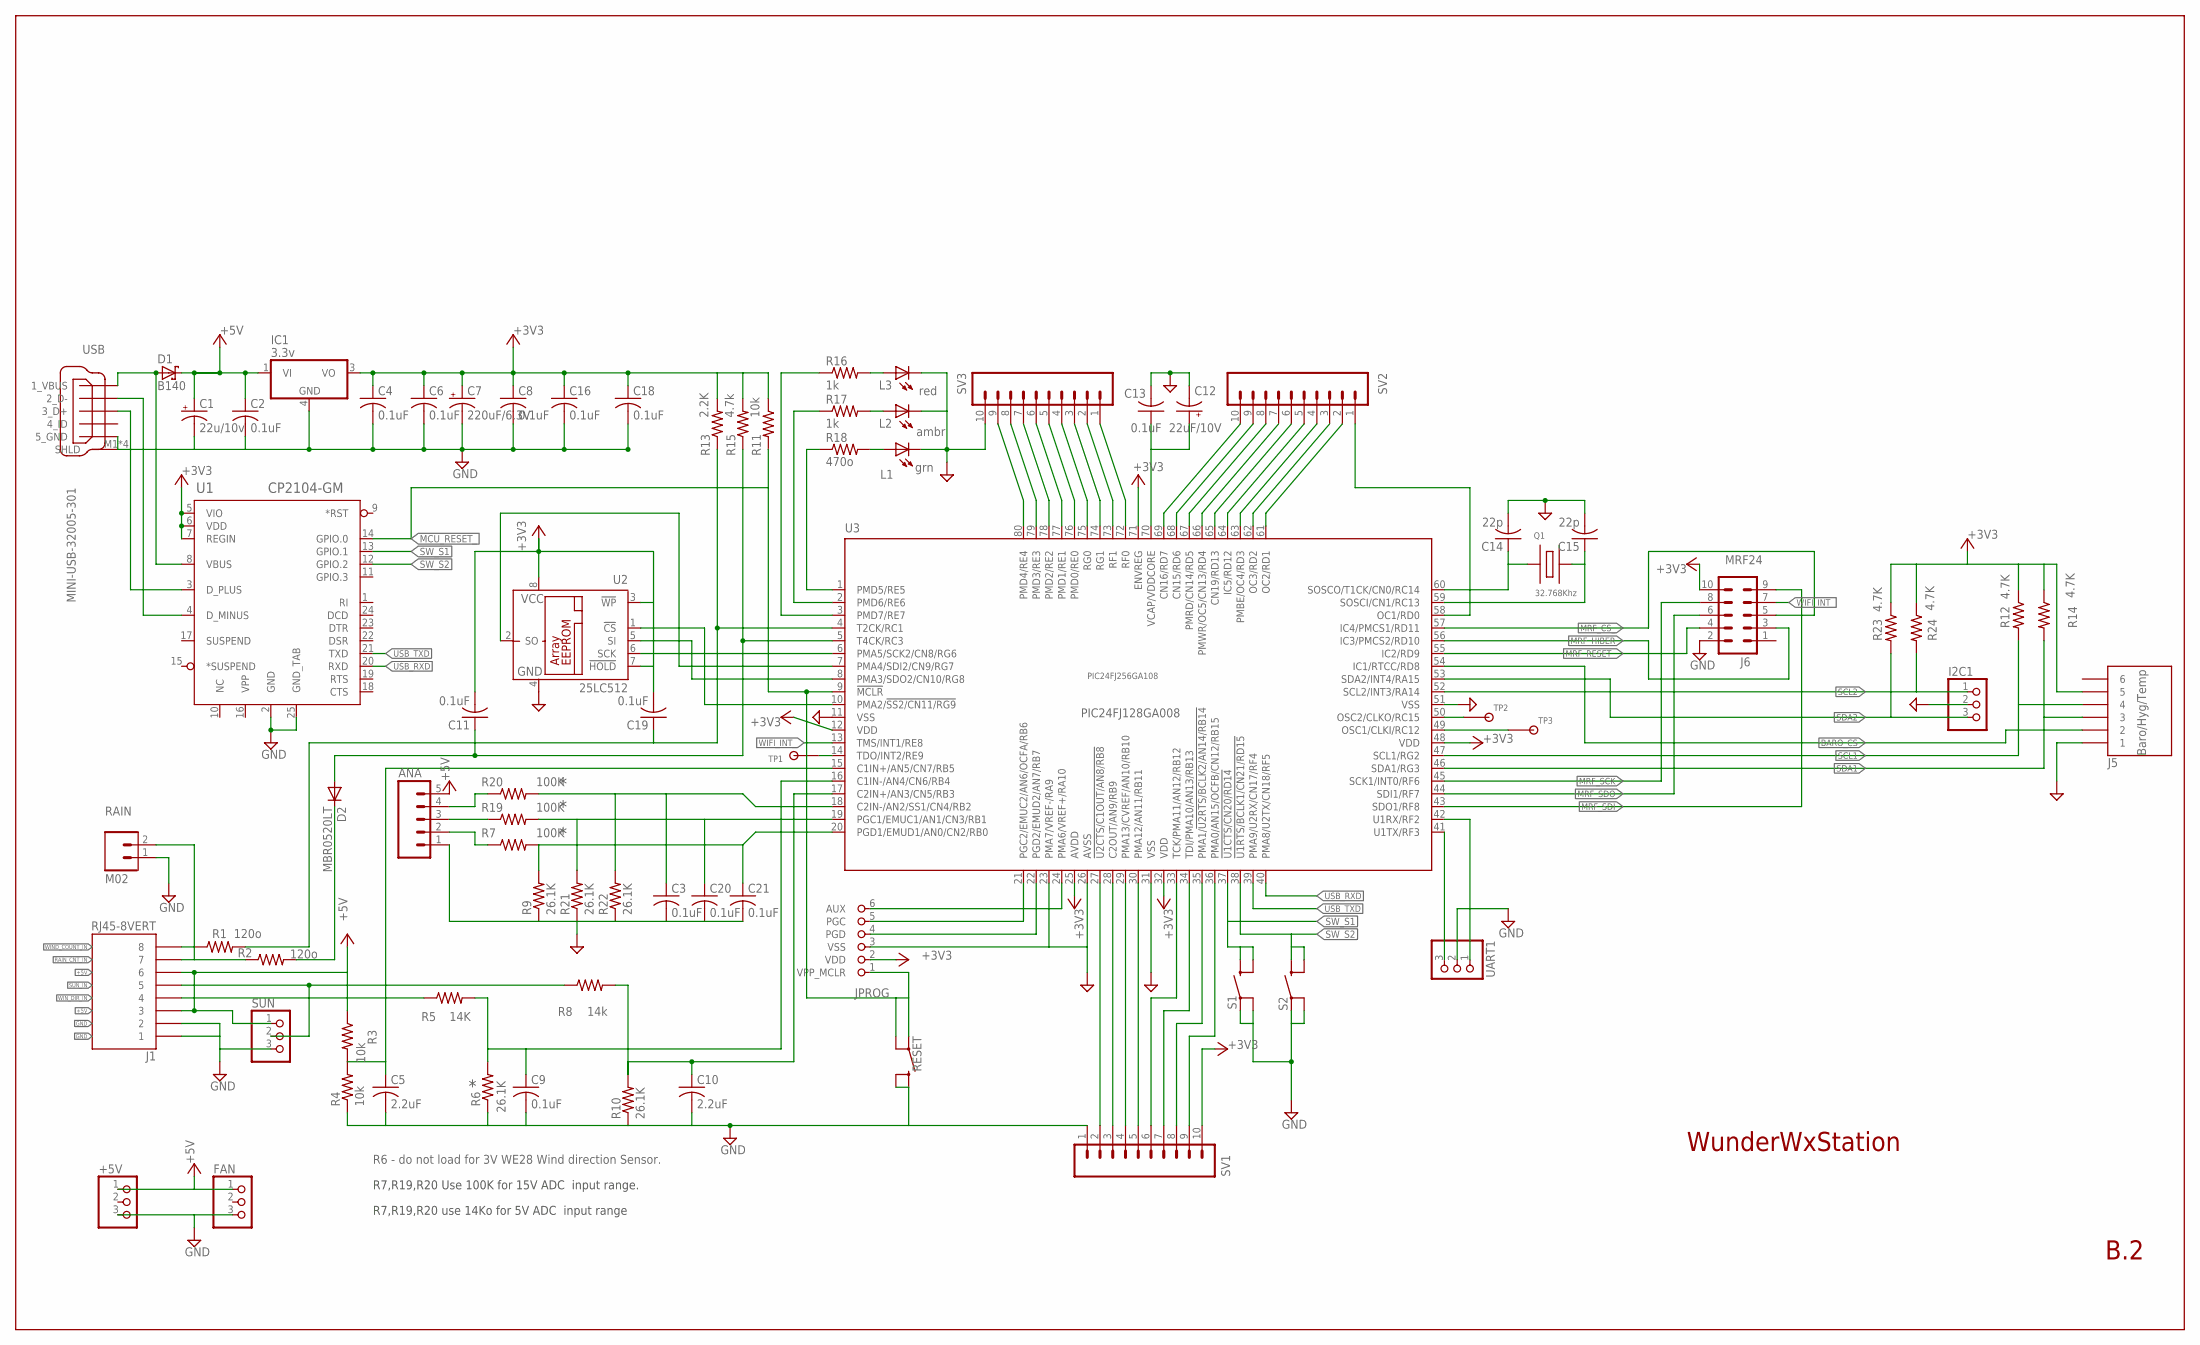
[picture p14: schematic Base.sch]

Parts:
+5V: PINHD-1X3MOLEX_KK; 1X3_MOLEX_KK
ANA: M05PTH; 1X05
C1: 22u/10v; SMC_B
C2, C3, C4, C6, C8, C9, C11, C13, C16, C18, C19, C20, C21: 0.1uF; C0805
C5, C10: 2.2uF; C0805
C7: 220uF/6.3V; SMC_D
C12: 22uF/10V; SMC_B
C14, C15: 22p; C0603
D1: B140; SMB
D2: MBR0520LT; SOD123
FAN: PINHD-1X3MOLEX_KK; 1X3_MOLEX_KK
I2C1: PINHD-1X3; 1X03
IC1: 3.3v; DPACK
J1: RJ45-8VERT; RJ45_VERT
J5: RJ11-6VERT_LP; RJ11-6-VERT
J6: M05X22X5FE; 2X5FEMALE
JPROG: PIKIT2_PRG; 1X06_PIKIT
L1: grn; CHIP-LED0603
L2: ambr; CHIP-LED0603
L3: red; CHIP-LED0603
Q1: 32.768Khz; CRYSTAL32_SMT
R1, R2: 120o; R0603
R3, R4, R11: 10k; R0603
R5: 14K; R0603
R6, R9, R10, R21, R22: 26.1K; R0603
R7, R19, R20: 100K; R0603
R8: 14k; R0603
R12, R14, R23, R24: 4.7K; R0603
R13: 2.2K; R0603
R15: 4.7k; R0603
R16, R17: 1k; R0603
R18: 470o; R0603
RAIN: M02; 1X02
RESET: SWITCH-MOMENTARY-2SMD; TACTILE_SWITCH_SMD
S1, S2: SWITCH-MOMENTARY-2SMD; TACTILE_SWITCH_SMD
SUN: PINHD-1X3MOLEX_KK; 1X3_MOLEX_KK
SV1, SV2, SV3: M10"; 1X10
TP1: TP10R
TP2, TP3: TP6R; TP06R
U1: CP2104-GM; QFN24_4X4
U2: 25LC512; SO-08
U3: PIC24FJ128GA008; TQFP80-12X12
UART1: PINHD-1X3; 1X03
USB: MINI-USB-32005-301; 32005-301

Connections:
+3V3: C4.1, C6.1, C7.+, C8.1, C11.2, C16.1, C18.1, C19.2, IC1.3 (VO), J5.P$5 (5), J6.10, JPROG.2 (VDD), R11.1, R12.1, R13.2, R14.1, R15.2, R23.1, R24.1, SV1.10, U1.5 (VIO), U1.6 (VDD), U1.7 (REGIN), U2.3 (!WP), U2.7 (!HOLD), U2.8 (VCC), U3.12 (VDD), U3.25 (AVDD), U3.32 (VDD), U3.48 (VDD), U3.71 (ENVREG)
+5V: +5V.1, ANA.5, C1.+, C2.1, D1.C, FAN.1, IC1.1 (VI), J1.P$3 (3), J1.P$6 (6), R3.1, SUN.1
BARO_CS: J5.P$2 (2), U3.54 (IC1/RTCC/RD8)
GND: +5V.3, ANA.1, C1.-, C2.2, C3.2, C4.2, C5.2, C6.2, C7.-, C8.2, C9.2, C10.2, C12.-, C13.2, C14.2, C15.2, C16.2, C18.2, C20.2, C21.2, FAN.3, I2C1.2, IC1.4 (GND), J1.P$1 (1), J1.P$2 (2), J5.P$1 (1), J6.2, JPROG.3 (VSS), L1.C, L2.C, L3.C, R4.1, R6.1, R9.1, R10.1, R21.1, R22.1, RAIN.1, RESET.3 (2), RESET.4 (3), S1.1, S1.2 (4), S2.1, S2.2 (4), SUN.3, SV1.1, SV3.10, U1.2 (GND), U1.25 (GND_TAB), U2.4 (GND), U3.11 (VSS), U3.23 (PMA7/VREF-/RA9), U3.26 (AVSS), U3.31 (VSS), U3.51 (VSS), UART1.2, USB.5_USB_GND (5_GND), USB.M1 (SHLD), USB.M2 (SHLD), USB.M3 (SHLD), USB.M4 (SHLD)
MCU_RESET_: JPROG.1 (VPP_MCLR), R11.2, RESET.1, RESET.2 (4), U1.14 (GPIO.0), U3.9 (!MCLR)
MRF_CS_: J6.5, U3.57 (IC4/PMCS1/RD11)
MRF_HIBER: J6.3, U3.56 (IC3/PMCS2/RD10)
MRF_RESET_: J6.4, U3.55 (IC2/RD9)
MRF_SCK: J6.8, U3.45 (SCK1/INT0/RF6)
MRF_SDI: J6.9, U3.43 (SDO1/RF8)
MRF_SDO: J6.6, U3.44 (SDI1/RF7)
unnamed: D2.C, R2.2
unnamed: C15.1, Q1.P$3, U3.59 (SOSCI/CN1/RC13)
unnamed: TP2.TP_1, U3.50 (OSC2/CLKO/RC15)
unnamed: R18.1, U3.1 (PMD5/RE5)
unnamed: C14.1, Q1.P$2, U3.60 (SOSCO/T1CK/CN0/RC14)
unnamed: TP1.TP_1, U3.14 (TDO/INT2/RE9)
unnamed: D1.A, U1.8 (VBUS), USB.1_VBUS
unnamed: SV2.2, U3.61 (OC2/RD1)
unnamed: SV2.3, U3.62 (OC3/RD2)
unnamed: SV2.4, U3.63 (PMBE/OC4/RD3)
unnamed: SV2.5, U3.64 (IC5/RD12)
unnamed: TP3.TP_1, U3.49 (OSC1/CLKI/RC12)
unnamed: SV2.6, U3.65 (CN19/RD13)
unnamed: JPROG.5 (PGC), U3.21 (PGC2/EMUC2/AN6/OCFA/RB6)
unnamed: JPROG.4 (PGD), U3.22 (PGD2/EMUD2/AN7/RB7)
unnamed: L3.A, R16.2
unnamed: C12.+, C13.1, U3.70 (VCAP/VDDCORE)
unnamed: L2.A, R17.2
unnamed: L1.A, R18.2
unnamed: C21.1, R7.2, R9.2, U3.20 (PGD1/EMUD1/AN0/CN2/RB0)
unnamed: ANA.4, R20.1
unnamed: C20.1, R19.2, R21.2, U3.19 (PGC1/EMUC1/AN1/CN3/RB1)
unnamed: U2.2 (SO), U3.7 (PMA4/SDI2/CN9/RG7)
unnamed: SV2.7, U3.66 (PMWR/OC5/CN13/RD4)
unnamed: U2.1 (!CS), U3.10 (PMA2/!SS2/CN11/RG9)
unnamed: C3.1, R20.2, R22.2, U3.18 (C2IN-/AN2/SS1/CN4/RB2)
unnamed: U2.6 (SCK), U3.6 (PMA5/SCK2/CN8/RG6)
unnamed: ANA.3, R19.1
unnamed: ANA.2, R7.1
unnamed: U2.5 (SI), U3.8 (PMA3/SDO2/CN10/RG8)
unnamed: R17.1, U3.2 (PMD6/RE6)
unnamed: R16.1, U3.3 (PMD7/RE7)
unnamed: SV2.8, U3.67 (PMRD/CN14/RD5)
unnamed: SV2.9, U3.68 (CN15/RD6)
unnamed: SV2.10, U3.69 (CN16/RD7)
unnamed: SV3.1, U3.72 (RF0)
unnamed: SV2.1, U3.58 (OC1/RD0)
unnamed: U3.41 (U1TX/RF3), UART1.3
unnamed: U3.42 (U1RX/RF2), UART1.1
unnamed: SV1.2, U3.27 (!U2CTS/C1OUT/AN8/RB8)
unnamed: SV1.3, U3.28 (C2OUT/AN9/RB9)
unnamed: SV1.4, U3.29 (PMA13/CVREF/AN10/RB10)
unnamed: SV1.5, U3.30 (PMA12/AN11/RB11)
unnamed: SV1.6, U3.33 (TCK/PMA11/AN12/RB12)
unnamed: SV1.7, U3.34 (TDI/PMA10/AN13/RB13)
unnamed: SV1.8, U3.35 (PMA1/!U2RTS/BCLK2/AN14/RB14)
unnamed: SV1.9, U3.36 (PMA0/AN15/OCFB/CN12/RB15)
unnamed: SV3.2, U3.73 (RF1)
unnamed: SV3.3, U3.74 (RG1)
unnamed: SV3.4, U3.75 (RG0)
unnamed: SV3.5, U3.76 (PMD0/RE0)
unnamed: SV3.6, U3.77 (PMD1/RE1)
unnamed: SV3.7, U3.78 (PMD2/RE2)
unnamed: SV3.8, U3.79 (PMD3/RE3)
unnamed: SV3.9, U3.80 (PMD4/RE4)
unnamed: JPROG.6 (AUX), U3.24 (PMA6/VREF+/RA10)
unnamed: C5.1, R3.2, R4.2, U3.15 (C1IN+/AN5/CN7/RB5)
RAIN_CNT_IN: J1.P$7 (7), R2.1, RAIN.2
RAIN_COUNT: C11.1, D2.A, R15.1, U3.5 (T4CK/RC3)
SCL1: J5.P$4 (4), R12.2, U3.47 (SCL1/RG2)
SCL2: I2C1.1, R24.2, U3.52 (SCL2/INT3/RA14)
SDA1: J5.P$3 (3), R14.2, U3.46 (SDA1/RG3)
SDA2: I2C1.3, R23.2, U3.53 (SDA2/INT4/RA15)
SUN_ADC_IN: C10.1, R8.2, R10.2, U3.17 (C2IN+/AN3/CN5/RB3)
SUN_IN: J1.P$5 (5), R8.1, SUN.2
SW_S1: S1.3 (2), S1.4 (3), U1.13 (GPIO.1), U3.37 (!U1CTS/CN20/RD14)
SW_S2: S2.3 (2), S2.4 (3), U1.12 (GPIO.2), U3.38 (!U1RTS/BCLK1/CN21/RD15)
USB_D+: U1.3 (D_PLUS), USB.3_D+
USB_D-: U1.4 (D_MINUS), USB.2_D-
USB_RXD: U1.20 (RXD), U3.40 (PMA8/U2TX/CN18/RF5)
USB_TXD: U1.21 (TXD), U3.39 (PMA9/U2RX/CN17/RF4)
WIFI_INT_: J6.7, U3.13 (TMS/INT1/RE8)
WIND_ADC_IN: C9.1, R5.2, R6.2, U3.16 (C1IN-/AN4/CN6/RB4)
WIND_COUNT: C19.1, R1.2, R13.1, U3.4 (T2CK/RC1)
WIND_COUNT_IN: J1.P$8 (8), R1.1
WIN_DIR_IN: J1.P$4 (4), R5.1

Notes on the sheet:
Baro/Hyg/Temp
PIC24FJ256GA108
MRF24
R6 - do not load for 3V WE28 Wind direction Sensor.
B.2
WunderWxStation
R7,R19,R20 Use 100K for 15V ADC input range.
R7,R19,R20 use 14Ko for 5V ADC input range

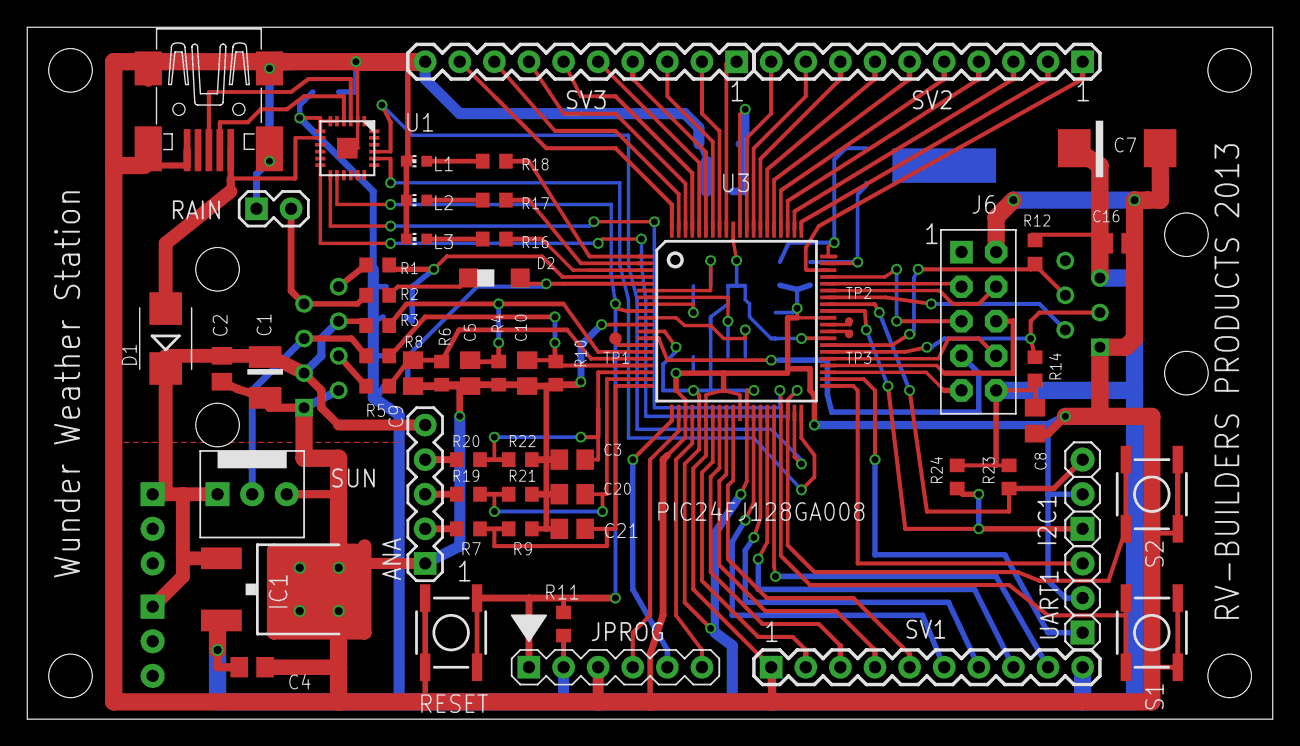
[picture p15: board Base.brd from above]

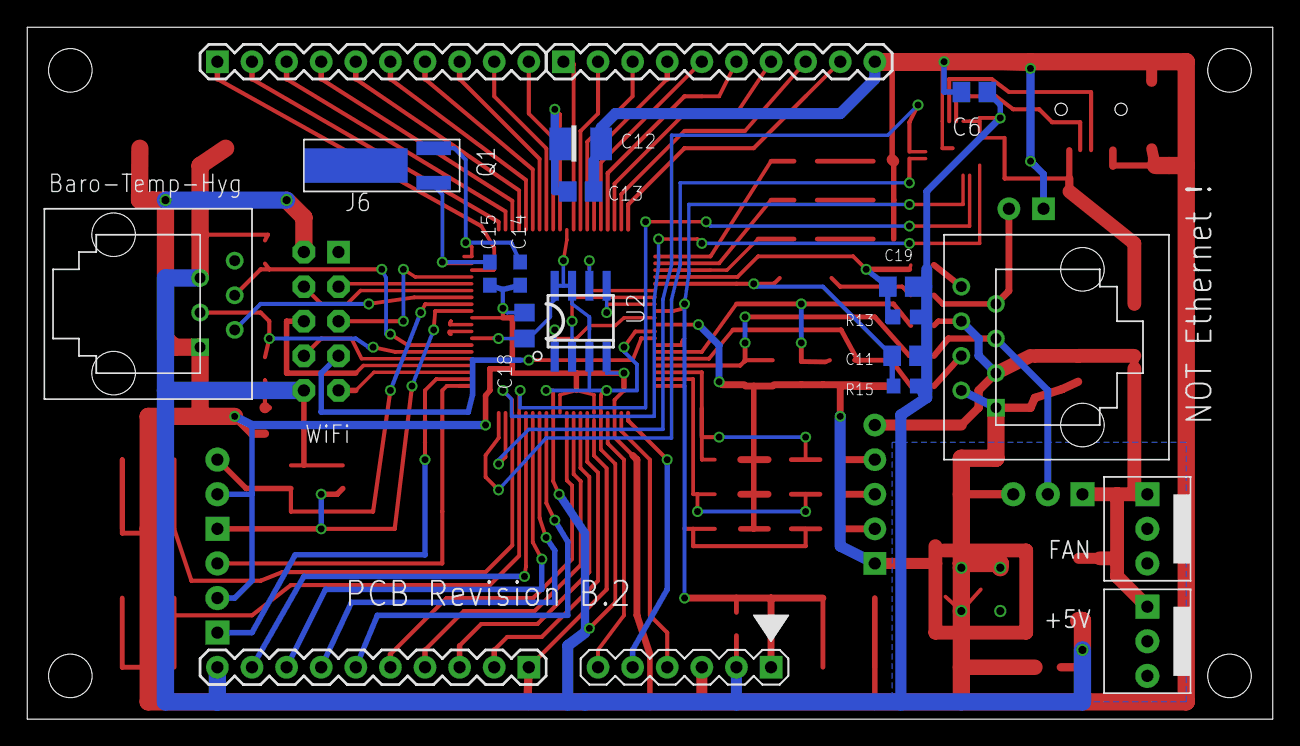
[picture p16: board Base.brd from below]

Board: 2 copper layers, 91.4 x 50.8 mm, 75 parts (20 on the bottom side), 87 nets.

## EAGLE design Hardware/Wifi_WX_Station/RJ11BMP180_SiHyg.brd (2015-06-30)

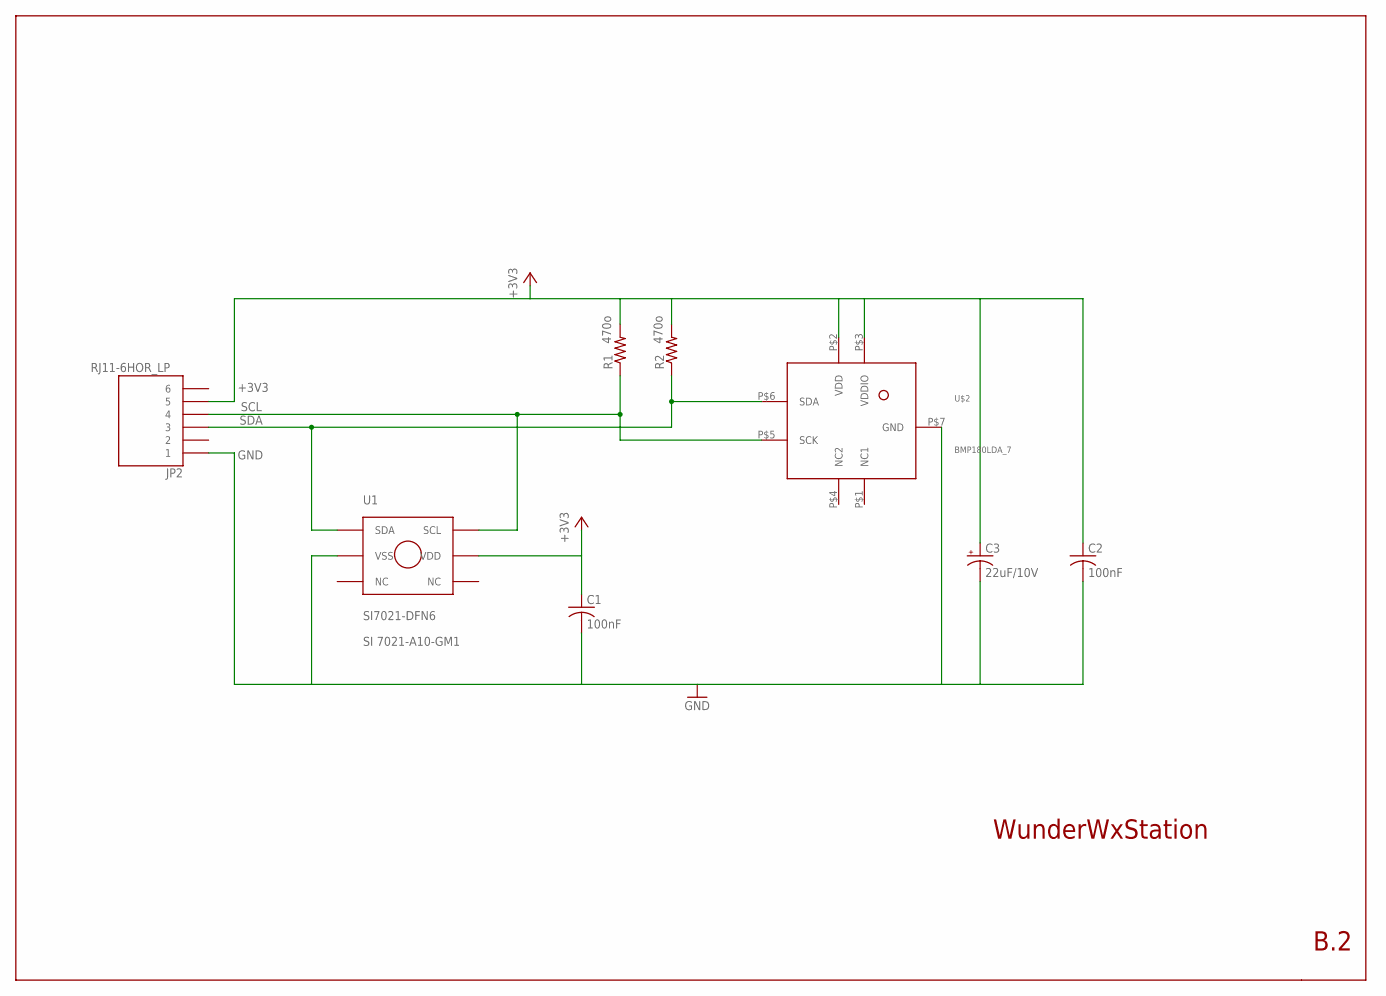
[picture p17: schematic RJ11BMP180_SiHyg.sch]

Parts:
C1, C2: 100nF; C0805K
C3: 22uF/10V; SMC_B
JP2: RJ11-6HOR_LP; RJ11_HOR_LP
R1, R2: 470o; R0603
U1: SI7021-DFN6; DFN-6_SILABS
U$2: BMP180LDA_7; LGA_7

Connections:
+3V3: C1.1, C2.1, C3.+, JP2.P$5 (5), R1.2, R2.2, U1.P$5 (VDD), U$2.P$2 (VDD), U$2.P$3 (VDDIO)
GND: C1.2, C2.2, C3.-, JP2.P$1 (1), U1.P$2 (VSS), U$2.P$7 (GND)
SCL: JP2.P$4 (4), R1.1, U1.P$6 (SCL), U$2.P$5 (SCK)
SDA: JP2.P$3 (3), R2.1, U1.P$1 (SDA), U$2.P$6 (SDA)

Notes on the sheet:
WunderWxStation
B.2
SI 7021-A10-GM1

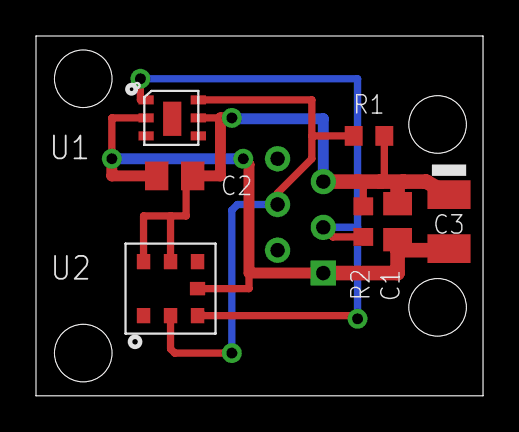
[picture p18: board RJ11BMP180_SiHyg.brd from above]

Board: 2 copper layers, 24.8 x 20.0 mm, 8 parts (1 on the bottom side), 4 nets.

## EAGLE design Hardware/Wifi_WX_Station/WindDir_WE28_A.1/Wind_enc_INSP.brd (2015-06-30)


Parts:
C1: 1uf; C0805K
C5: 1uF; C0805K
IC1: EM3242; EM3242_SPECIAL
IC2: TLV2211; SOT23-5
IC3: TC10553.3V; SOT23-5
R1: 100k; R0603
R2: 150k; R0603
R3: 24.3k; R0603
R4: 14.3k; R0603
R5: 330; R0603
R6: 0; R0603
X1: 1751251

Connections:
unnamed: C5.1, IC2.5 (VDD), IC3.1 (IN), IC3.3 (EN), R6.1, X1.1
unnamed: C1.2, C5.2, IC1.1 (TSTB), IC1.2 (VSS), IC1.6 (TSTA), IC2.2 (VDD_GND), IC3.2 (GND), R2.2, X1.2
unnamed: R5.1, X1.3
unnamed: IC1.4 (AOUT), R4.2
unnamed: C1.1, IC1.3 (PDN), IC1.5 (VDD), IC3.5 (OUT), R1.1, R6.2
unnamed: IC2.3 (-IN), R3.2, R4.1
unnamed: IC2.4 (OUT), R3.1, R5.2
unnamed: IC2.1 (+IN), R1.2, R2.1

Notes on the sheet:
Wind Encoder WE28
IC2
R6: Do Not populate -- For 3.3V input voltage operation only, when IC3 is removed.
A.1
R1,R2,R3,R4 Panasonic , 25ppm , 0.1%
R2: P150KDBCT-ND
R1: P100KDBCT-ND
R3: P24.3KDBCT-ND
R4: P14.3KDBCT-ND
Output Voltage 0.3 - 4.78V
Input Voltage 5 - 12V
Output Voltage 0.1 - 3.3V
R1,R2,R3,R4 Panasonic , 25ppm , 0.1%
R1.R2, P100KDBCT-ND
R3,R4 P24.3KDBCT-ND
NOTE: Resistive load >= 20Kohms only



Board: 2 copper layers, 25.4 x 25.3 mm, 12 parts (3 on the bottom side), 8 nets.

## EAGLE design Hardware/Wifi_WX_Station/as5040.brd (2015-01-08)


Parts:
+5V: TPSOL; TP_SOL
A_LSB_U: TPSOL; TP_SOL
B-DIR_V: TPSOL; TP_SOL
C1, C5: 1uF; C0805K
CLK: TPSOL; TP_SOL
CS_: TPSOL; TP_SOL
DO: TPSOL; TP_SOL
GND: TPSOL; TP_SOL
MAG+: TPSOL; TP_SOL
MAG-: TPSOL; TP_SOL
NDX_W: TPSOL; TP_SOL
PROG: TPSOL; TP_SOL
PWM_LSB: TPSOL; TP_SOL
U$2: AS5040; AMS_5040_SPECIAL
V3_3: TPSOL; TP_SOL

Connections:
unnamed: C1.2, C5.2, GND.P$1, U$2.P$7 (VSS)
unnamed: +5V.P$1, C5.1, U$2.P$16 (VDD5V)
unnamed: C1.1, U$2.P$15 (VDD3V3), V3_3.P$1
unnamed: MAG+.P$1, U$2.P$1 (MAG_INC)
unnamed: MAG-.P$1, U$2.P$2 (MAG_DEC)
unnamed: A_LSB_U.P$1, U$2.P$3 (A_LSB_U)
unnamed: B-DIR_V.P$1, U$2.P$4 (B_DIR_V)
unnamed: NDX_W.P$1, U$2.P$6 (INDEX_W)
unnamed: PROG.P$1, U$2.P$8 (PROG)
unnamed: PWM_LSB.P$1, U$2.P$12 (PWM_LSB)
unnamed: CS_.P$1, U$2.P$11 (CS_)
unnamed: CLK.P$1, U$2.P$10 (CLK)
unnamed: DO.P$1, U$2.P$9 (DO)


Board: 2 copper layers, 25.4 x 25.3 mm, 16 parts (0 on the bottom side), 13 nets.

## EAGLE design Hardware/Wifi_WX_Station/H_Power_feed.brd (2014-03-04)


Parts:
J1, J2: RJ45-8PTH; RJ45-8
RAIN: PINHD-1X3MOLEX_KK; 1X3_MOLEX_KK
SUN: PINHD-1X3MOLEX_KK; 1X3_MOLEX_KK
USB: MINI-USB-32005-301; 32005-301

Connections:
+5V: J1.3, J1.6, J2.3, J2.6, RAIN.1, SUN.1, USB.1_VBUS
GND: J1.1, J1.2, J2.1, J2.2, RAIN.3, SUN.3, USB.5_USB_GND (5_GND), USB.M1 (SHLD), USB.M2 (SHLD), USB.M3 (SHLD), USB.M4 (SHLD)
RAIN_CNT_IN: J1.7, J2.7, RAIN.2
SUN_IN: J1.5, J2.5, SUN.2
WIND_COUNT: J1.8, J2.8
WIN_DIR_IN: J1.4, J2.4

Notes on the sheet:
WunderWxSation
B.2


Board: 2 copper layers, 35.2 x 37.5 mm, 5 parts (0 on the bottom side), 6 nets.

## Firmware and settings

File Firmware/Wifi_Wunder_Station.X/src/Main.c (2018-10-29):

/*************************************************************************
 *
 * Main file for WX-Wunder Station
 *
 *
 *************************************************************************/
#define THIS_IS_STACK_APPLICATION

// Include all headers for any enabled TCPIP Stack functions
#include "TCPIP Stack/TCPIP.h"
#include "APP_cfg.h"
#include "WX_perm_data.h"
#include "rtcc.h"
#include "nist.h"
#include "Mail_Alarm.h"
#include "Main.h"
#include "HW_initialize.h"
#include "Once_per_second.h"
#include "Barometer.h"
#include "Hygrometer.h"
#include "WunderHttpClient.h"

#include "Configs/WX_WUNDER_BRD_MRF24W.h"       // to make the IDE's error checking happy  (if defined (WS_CS_TRIS) -- Already included by compiler
#include "Configs/TCPIP MRF24W.h"               // ""
#define APRS_WIFICONNECT_TIME 7200 // time the system waits until it gives up trying to connect to a accesspoint in APRS_RF mode 7200 == 3 minutes

#if defined(WF_CS_TRIS) &&  !defined(MRF24WG)
 extern BOOL gRFModuleVer1209orLater;
#endif

// Application is written for C30 compiler and PIC24F family 
#if !defined (__C30__)
#error "This project needs to be compiled with a C30 compiler!"
#endif
#if !defined(__PIC24F__)
#error "This Project is for a PIC24F family device"
#endif

#if !defined(WF_CS_TRIS)
#error "This project requires a WiFi netwotk access controller"
#endif

#if defined(STACK_USE_ZEROCONF_LINK_LOCAL)
#include "TCPIP Stack/ZeroconfLinkLocal.h"
#endif
#if defined(STACK_USE_ZEROCONF_MDNS_SD)
#include "TCPIP Stack/ZeroconfMulticastDNS.h"
#endif

// Used for Wi-Fi assertions
#define WF_MODULE_NUMBER   WF_MODULE_MAIN_DEMO

/* BOOTLOADER stuff
        Store Boot loader delay timeout value & user reset vector at 0x100
        (can't be used with bootloader's vector protect mode).

        Value of userReset should match reset vector as defined in linker script.
        BLreset space must be defined in linker script.
*/
unsigned int userReset  __attribute__ ((space(prog),section(".BLreset"))) = 0xC00 ;
unsigned char BL_timeout  __attribute__ ((space(prog),section(".BLreset"))) = 0x0 ; // Boot loader listens for bootloader app on UART for "n" seconds
// End of Bootloader Stuff


// traps for system errors -- useful for debugging
 
void _ISR __attribute__((__no_auto_psv__))
_AddressError(void)
{
    Nop();
    Nop();
}

void _ISR __attribute__((__no_auto_psv__))
_StackError(void)
{
    Nop();
    Nop();
}
/* Interrupt service routine to handle the pin change notification interrupt
 Change Notification is used to trigger mail alarms when a active high signal is detected on an active alarm
 input
 */
volatile unsigned short tmp;


void _ISR __attribute__((__no_auto_psv__))
_CNInterrupt(void)
{
    unsigned short alarms = 0;

    tmp = PORTD;


    // Alarms are triggered on active high signal on the enabled  alarm inputs

    if (( WX.Alarms.enable & 1<<1) && ALARM_1_input)
        alarms |= 1<<1;

    if ( (WX.Alarms.enable & 1<<2) && ALARM_2_input)
        alarms |= 1<<2;

    if ( (WX.Alarms.enable & 1<<3) && ALARM_3_input)
        alarms |= 1<<3;

    if ( (WX.Alarms.enable & 1<<4) && ALARM_4_input)
        alarms |= 1<<4;

    if ( (WX.Alarms.enable & 1<<5) && ALARM_5_input)
        alarms |= 1<<5;

   if (alarms )
     SMTP_set_alarm(alarms);

   IFS1bits.CNIF =0;
}
static void
Display_MAC_Addr( void )
{
    BYTE digit;
    BYTE i;

    putrsUART("MAC Address: ");

    for (i = 0; i < sizeof (MAC_ADDR); i++)
    {
        if (i)
            putcUART(':');
        digit = btohexa_high(AppConfig.MyMACAddr.v[i]);
        putcUART(digit);
        digit = btohexa_low(AppConfig.MyMACAddr.v[i]);
        putcUART(digit);

    }

    putrsUART("\r\n");
}
 

// Writes an IP address to the UART 
void
DisplayIPValue(IP_ADDR IPVal)
{
    //	printf("%u.%u.%u.%u", IPVal.v[0], IPVal.v[1], IPVal.v[2], IPVal.v[3]);

    BYTE IPDigit[4];
    BYTE i;

    for (i = 0; i < sizeof (IP_ADDR); i++)
    {
        uitoa((WORD) IPVal.v[i], IPDigit);
        putsUART((char *) IPDigit);

        if (i == sizeof (IP_ADDR) - 1)
            break;

        while (BusyUART())
            ;
        WriteUART('.');
    }

}

static void
Announce_My_IP_addr(void)
{
    static DWORD My_last_IP_addr = 0;

    // If the local IP address has changed (ex: due to DHCP lease change)
    // write the new IP address to the LCD display, UART, and Announce
    // service

    if (My_last_IP_addr != AppConfig.MyIPAddr.Val)
    {
        My_last_IP_addr = AppConfig.MyIPAddr.Val;
        putrsUART((ROM char*) "\r\nIP Address: ");
        DisplayIPValue(AppConfig.MyIPAddr);
        putrsUART((ROM char*) "\r\n");

#if defined(STACK_USE_ANNOUNCE)
        AnnounceIP(); // This is for the Microchip TCPIP discover tool
#endif

#if defined(STACK_USE_ZEROCONF_MDNS_SD)
        mDNSFillHostRecord();
#endif
    }
}

//
// Main application entry point.
//

int
main(void)
{
    unsigned short WiFi_con_watchdog;  // This is a work around for the problem when the WIFI board crashes and stops sending interrupts
    g_isPSK_Ready = 0;


    // Initialize application specific hardware
    InitializeBoard();
  
    // Initialize stack-related hardware components that may be
    // required by the UART configuration routines
    TickInit();

#if defined(STACK_USE_MPFS2)
    MPFSInit();             // EEprom or Flash Files System init
#endif

    // Initialize Stack and application related NV variables into AppConfig.
    InitAppConfig();

    putrsUART("\f");
    putrsUART("*** WiFi Wunder Weather Station ***\r\n\r\n");
    putrsUART("To restore factory defaults press and hold S1 for > 4 seconds during reset.\r\n");
    putrsUART("To enter configuration utility press and hold S1 for < 4 seconds during reset.\r\n\r\n");

  
    All_LEDS_off();

    // Resets board to factory values if button is depressed on start-up and allows UART based communication configuration
    if (BUTTON1_IO == 0u)
    {
#if defined(EEPROM_CS_TRIS) || defined(SPIFLASH_CS_TRIS)
        // Invalidate the EEPROM contents if BUTTON0 is held down for more than 4 seconds
        DWORD StartTime = TickGet();

        while (BUTTON1_IO == 0u)
        {
            if (TickGet() - StartTime > 4 * TICK_SECOND)
            {

                putrsUART("\r\n\r\nButton S1 held for > 4 seconds.  Default settings restored.\r\n\r\n");

                while (BUTTON1_IO == 0u)
                {
                    DelayMs(100);
                    All_LEDS_on();
                    DelayMs(100);
                    All_LEDS_off();
                }

                InvalidateAppConfig();
                WX_perm_data_init_toDefault();
                Reset();
                break;
            }
        }

#endif
        LED2_IO = 1;
        DoUARTConfig(); // This is a RS232 based configuration option
        LED2_IO = 0;

    }

   
   
//  WX_perm_data_init_toDefault();  To force the default config during debugging
    WX_readPerm_data(); // Get the station NV data from EEprom

    Display_MAC_Addr( );
    putrsUART("User Name and Password:");
    putsUART(WX.Station.User_name);
    putrsUART(",");
    putsUART(WX.Station.password);
    putrsUART("\r\n");
    putrsUART("Netbios name: ");putsUART(AppConfig.NetBIOSName);
    putrsUART("WiFi SSID: ");putsUART(AppConfig.MySSID);
    putrsUART("\r\n\r\n");
   

    Baro_init(WX.Wunder.StationElev); // must be done after we read the WX_perm_data
    Hygro_init();

    StackInit(); // Initialize core stack layers (MAC, ARP, TCP, UDP) and application modules (HTTP, SNMP, etc.)

    // For APRS_RF only configure a limited number of connection attempts -- otherwise attempt to connect forever
    // this is so that the station doesn't try to connect to wifi forever and therefore waste power

    WF_Connect(WF_RETRY_FOREVER); // forever or until we reboot

    WiFi_con_watchdog = 0;
    putrsUART("\r\nInit complete... waiting for WiFi connection...\r\n");

    if (AppConfig.SecurityMode == WF_SECURITY_WPA_WITH_PASS_PHRASE ||
        AppConfig.SecurityMode == WF_SECURITY_WPA2_WITH_PASS_PHRASE ||
        AppConfig.SecurityMode == WF_SECURITY_WPA_AUTO_WITH_PASS_PHRASE)
    {
        g_isPSK_Ready = -1;     // in ecryption mode
        putrsUART("Waiting for WPA Passphrase encryption.....\r\nThis takes about 1 Minute. Do not interrupt!.\r\n");
    }

 
    SMTP_Alarm_Arm( WX.Alarms.enable & 0x1); // ARM or Disarm
 
    // Begin of the co-operative multitasking loop.
    while (1)
    {
        // This task performs normal stack task including checking
        // for incoming packet, type of packet and calling
        // appropriate stack entity to process it.
        StackTask();        // StackTask also calls MACProcess which in terms calls WFProcess

        if (WX.Wunder.report_enable.Station != APRS_CLIENT)
        {

            if (!WiFi_isConnected()) // if there is no WIFI connection there is no use to do anything else
            {
                WiFi_con_watchdog++;
                DelayMs(25);// blink fast
                LED1_IO ^= 1;
                if ( WiFi_con_watchdog > 24000) // That's 10 minutes worth of (25ms) delays with no connection
                {
                     putrsUART("WiFi connection failed to establish for 10 minutes -- Rebooting. \r\n");
                     Reset(); // This would get triggered in case there is no connection with a access point for >10 min.
                              // This can also be the case if the Wifi Adapter crashes internally
                }
                else if ( WiFi_con_watchdog %1000 == 0)
                putrsUART("... waiting for WiFi connection...\r\n");
                continue;       // Nothing else is getting done until we have a WiFi connection
            }
        }
        else // it is the APRS_RF mode -- No Wifi Connection is required
        {
            if (WiFi_isConnected())
                    goto WiFiStation;

            if (WiFi_con_watchdog < APRS_WIFICONNECT_TIME )
            {
                if ( !WiFi_isConnected() &&  (++WiFi_con_watchdog == APRS_WIFICONNECT_TIME))
                {
                    putrsUART("Disabling WiFi device\r\n");
                    WF_HibernateEnable();      // sets the chip enable of the wifi module to false, only reset of the board will get it back
                }
                else
                {
                    DelayMs(25);// blink fast
                    LED1_IO ^= 1;
                }
            }
             goto NoWiFiStation;
        }

WiFiStation:
#if defined (WF_USE_POWER_SAVE_FUNCTIONS)
#if !defined(MRF24WG)
        if (gRFModuleVer1209orLater)
            WiFiPowerSavingTask();
#endif
#endif


        // This tasks invokes each of the core stack application tasks
        StackApplications();

        // Wait until we have a valid DHCP setup if so enabled,
        // otherwise the Announce_My_IP address and following calls could use an conflicting
        // IP address on their initial calls, causing traffic collisions on the network.

        if (AppConfig.Flags.bIsDHCPEnabled && AppConfig.Flags.bInConfigMode)
        {
             DelayMs(15);// blink faster
             LED1_IO ^= 1;
             if ( WiFi_con_watchdog++ %2000 == 0)
                  putrsUART("... waiting for DHCP completion\r\n");
             
            continue;  // wait until DHCP is completed
        }

        Announce_My_IP_addr();      // For the TCPIP discover tool and the UART status message

#if defined(STACK_USE_ZEROCONF_LINK_LOCAL)
        ZeroconfLLProcess();
#endif

#if defined(STACK_USE_ZEROCONF_MDNS_SD)
        mDNSProcess();
        // Use this function to exercise service update function
        // HTTPUpdateRecord();
#endif

        SMTP_Mail_alarm();      // checks and sends mail alarms
        NIST_DAYTIME_Client();  // Start One-shot to get time from a NIST server and periodically calls NIST again to update time

        if (WDIR_cal_tmp.DoWindDirCal)
        {
            Wind_dir_cal();
            continue;
        }
NoWiFiStation:
        Baro_Read_Process();    // Reads the Barometer pressure and temp
        Hygro_Read_Process();   // Reads the Hygrometer

        if (RTC_1Sec_flag )     //  time yet
        {
            RTC_1Sec_flag = FALSE;
            Once_perSecTask();      // This is the main application task that starts measurements and computes readings and averages
        }

        // Note that only one client will be doing something, the other one will stay at Idle
        WunderHttpClient();     // This does all the rest of the protocols
        APRS_Client();          // this does CWOP/APRS and APRS/RF  


        // TODO: This could go somewhere else, i.e inside an event ??
        if (g_isPSK_Ready == 1) // encryption done and the Appconfig is updated ( with MRF24W_G )
        {
            g_isPSK_Ready = 0;
            putrsUART("Storing WPA encryption key for future use \r\n");
            SaveAppConfig(&AppConfig);
        }

    } // end while for ever loop
}

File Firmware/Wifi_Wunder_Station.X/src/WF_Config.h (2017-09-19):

/******************************************************************************

 MRF24W Driver Customization
 Module for Microchip TCP/IP Stack
  -Provides access to MRF24W WiFi controller
  -Reference: MRF24W Data sheet, IEEE 802.11 Standard

*******************************************************************************
 FileName:		WF_Config.h
 Dependencies:	TCP/IP Stack header files
 Processor:		PIC18, PIC24F, PIC24H, dsPIC30F, dsPIC33F, PIC32
 Compiler:		Microchip C32 v1.10b or higher
				Microchip C30 v3.22 or higher
				Microchip C18 v3.34 or higher
 Company:		Microchip Technology, Inc.

 Software License Agreement

 Copyright (C) 2002-2010 Microchip Technology Inc.  All rights reserved.

 Microchip licenses to you the right to use, modify, copy, and distribute:
 (i)  the Software when embedded on a Microchip microcontroller or digital 
      signal controller product ("Device") which is integrated into 
      Licensee's product; or
 (ii) ONLY the Software driver source files ENC28J60.c, ENC28J60.h,
      ENCX24J600.c and ENCX24J600.h ported to a non-Microchip device used in 
	  conjunction with a Microchip ethernet controller for the sole purpose 
	  of interfacing with the ethernet controller.

 You should refer to the license agreement accompanying this Software for 
 additional information regarding your rights and obligations.

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

 Author				Date		Comment
~~~~~~~~~~~~~~~~~~~~~~~~~~~~~~~~~~~~~~~~~~~~~~~~~~~~~~~~~~~~~~~~~~~~~~~~~~~~~~~
 KH                 27 Jan 2010 Created for MRF24W
******************************************************************************/


#ifndef __WF_CONFIG_H_
#define __WF_CONFIG_H_

/*
*********************************************************************************************************
*                                           DEFINES                               
*********************************************************************************************************
*/

#define WF_TCPIP_DEMO



/*****************************************************************************/
/*****************************************************************************/
/*                             WIFI SECURITY COMPILE-TIME DEFAULTS           */
/*****************************************************************************/
/*****************************************************************************/
// Security modes available on WiFi network:
//   WF_SECURITY_OPEN                      : No security
//   WF_SECURITY_WEP_40                    : WEP Encryption using 40 bit keys
//   WF_SECURITY_WEP_104                   : WEP Encryption using 104 bit keys
//   WF_SECURITY_WPA_WITH_KEY              : WPA-PSK Personal where binary key is given to MRF24W 
//   WF_SECURITY_WPA_WITH_PASS_PHRASE      : WPA-PSK Personal where passphrase is given to MRF24W and it calculates the binary key
//   WF_SECURITY_WPA2_WITH_KEY             : WPA2-PSK Personal where binary key is given to MRF24W 
//   WF_SECURITY_WPA2_WITH_PASS_PHRASE     : WPA2-PSK Personal where passphrase is given to MRF24W and it calculates the binary key
//   WF_SECURITY_WPA_AUTO_WITH_KEY         : WPA-PSK Personal or WPA2-PSK Personal where binary key is given and MRF24W will 
//                                             connect at highest level AP supports (WPA or WPA2)                                                
//   WF_SECURITY_WPA_AUTO_WITH_PASS_PHRASE : WPA-PSK Personal or WPA2-PSK Personal where passphrase is given to MRF24W and it 
//                                             calculates the binary key and connects at highest level AP supports (WPA or WPA2)
//   WF_SECURITY_WPS_PUSH_BUTTON		   : WPS push button method
//   WF_SECURITY_WPS_PIN		   		   : WPS PIN method

//#define CFG_WF_INFRASTRUCTURE 1
//#define CFG_WF_P2P            3

#define MY_DEFAULT_NETWORK_TYPE             WF_INFRASTRUCTURE   /* CFG_WF_INFRASTRUCTURE, CFG_WF_P2P */
#define MY_DEFAULT_DOMAIN                   WF_DOMAIN_FCC
#define MY_DEFAULT_LIST_RETRY_COUNT         WF_RETRY_FOREVER            /* Number of times to try to connect to the SSID when using Infrastructure network type */

// Default pass phrase used for WF_SECURITY_WPA_WITH_PASS_PHRASE and
// WF_SECURITY_WPA2_WITH_PASS_PHRASE security modes
#define MY_DEFAULT_PSK_PHRASE  "dapassword"
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

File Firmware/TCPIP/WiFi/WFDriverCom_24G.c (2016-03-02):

/******************************************************************************

 MRF24W Driver Com Layer
 Module for Microchip TCP/IP Stack
  -Provides access to MRF24W WiFi controller
  -Reference: MRF24W Data sheet, IEEE 802.11 Standard

*******************************************************************************
 FileName:		WFDriverCom.c
 Dependencies:	TCP/IP Stack header files
 Processor:		PIC18, PIC24F, PIC24H, dsPIC30F, dsPIC33F, PIC32
 Compiler:		Microchip C32 v1.10b or higher
				Microchip C30 v3.22 or higher
				Microchip C18 v3.34 or higher
 Company:		Microchip Technology, Inc.

 Software License Agreement

 Copyright (C) 2002-2010 Microchip Technology Inc.  All rights reserved.

 Microchip licenses to you the right to use, modify, copy, and distribute:
 (i)  the Software when embedded on a Microchip microcontroller or digital 
      signal controller product ("Device") which is integrated into 
      Licensee's product; or
 (ii) ONLY the Software driver source files ENC28J60.c, ENC28J60.h,
      ENCX24J600.c and ENCX24J600.h ported to a non-Microchip device used in 
	  conjunction with a Microchip ethernet controller for the sole purpose 
	  of interfacing with the ethernet controller.

 You should refer to the license agreement accompanying this Software for 
 additional information regarding your rights and obligations.

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

 Author				Date		Comment
~~~~~~~~~~~~~~~~~~~~~~~~~~~~~~~~~~~~~~~~~~~~~~~~~~~~~~~~~~~~~~~~~~~~~~~~~~~~~~~
 KH                 27 Jan 2010 Updated for MRF24W
******************************************************************************/

/*
*********************************************************************************************************
*                                           INCLUDES                               
*********************************************************************************************************
*/

#include "TCPIP Stack/TCPIP.h"  // need this to access STACK_USE_DHCP_CLIENT define
#if defined(WF_CS_TRIS)



/*
*********************************************************************************************************
*                                           DEFINES      
*********************************************************************************************************
*/

/* used for assertions */
#if defined(WF_DEBUG)
    #define WF_MODULE_NUMBER    WF_MODULE_WF_DRIVER_COM
#endif

// HOST_RESET_REG masks
#define HR_CPU_RST_N_MASK                     ((UINT16)0x01 << 15)
#define HR_DISABLE_DOWNLOAD_SCRAMBLER_MASK    ((UINT16)0x01 << 14)
#define HR_FORCE_CPU_CLK_FREEZE_MASK          ((UINT16)0x01 << 13)
#define HR_HOST_ANA_SPI_EN_MASK               ((UINT16)0x01 << 12)
#define HR_HOST_ANA_SPI_DIN_MASK              ((UINT16)0x01 << 11)
#define HR_HOST_ANA_SPI_DOUT_MASK             ((UINT16)0x01 << 10)
#define HR_HOST_ANA_SPI_CLK_MASK              ((UINT16)0x01 << 9)
#define HR_HOST_ANA_SPI_CSN_MASK              ((UINT16)0x07 << 6)   // 8:6
#define HR_RESERVED_2_MASK                    ((UINT16)0x01 << 5)
#define HR_HOST_SPI_DISABLE_MASK              ((UINT16)0x01 << 4)
#define HR_HOST_ENABLE_NEW_PROG_MASK          ((UINT16)0x01 << 3)
#define HR_HOST_ENABLE_DOWNLOAD_MASK          ((UINT16)0x01 << 2)
#define HR_HOST_FAST_RESET_MASK               ((UINT16)0x01 << 1)
#define HR_HOST_RESET_MASK                    ((UINT16)0x01 << 0)

// This block of defines needed to restart PLL
#define ANALOG_PORT_3_REG_TYPE           ((UINT32)0x09)   /* 16-bit analog register in SPI Port 3                                          */
#define ANALOG_PORT_2_REG_TYPE           ((UINT32)0x08)   /* 16-bit analog register in SPI Port 2                                          */
#define ANALOG_PORT_1_REG_TYPE           ((UINT32)0x0a)   /* 16-bit analog register in SPI Port 1                                          */
#define ANALOG_PORT_0_REG_TYPE           ((UINT32)0x0b)   /* 16-bit analog register in SPI Port 0                                          */

#define SPI_WRITE_MASK                          (UINT8)0x00     // bit 0 = 0
#define SPI_READ_MASK                           (UINT8)0x01     // bit 0 = 1
#define SPI_AUTO_INCREMENT_ENABLED_MASK         (UINT8)0x00     // bit 1 = 0
#define SPI_AUTO_INCREMENT_DISABLED_MASK        (UINT8)0x02     // bit 1 = 1

#define PLL9_REG   ((UINT32)(9 * 2)) // SPI Port 3 Registers (Port 5 if going through Master SPI controller)
#define PLL8_REG   ((UINT32)(8 * 2))
#define PLL7_REG   ((UINT32)(7 * 2))
#define PLL6_REG   ((UINT32)(6 * 2)) 
#define PLL5_REG   ((UINT32)(5 * 2)) 
#define PLL4_REG   ((UINT32)(4 * 2)) 
#define PLL3_REG   ((UINT32)(3 * 2)) 
#define PLL2_REG   ((UINT32)(2 * 2)) 
#define PLL1_REG   ((UINT32)(1 * 2)) 
#define PLL0_REG   ((UINT32)(0 * 2)) 
// end PLL block

#define OSC0_REG   ((UINT32)(0 * 2)) 
#define OSC1_REG   ((UINT32)(1 * 2)) 
#define OSC2_REG   ((UINT32)(2 * 2)) 
#define PLDO_REG            ((UINT32)(3 * 2))
#define BIAS_REG            ((UINT32)(4 * 2))
#define ANALOG_SPARE_REG    ((UINT32)(5 * 2))

/*
*********************************************************************************************************
*                                       LOCAL GLOBAL VARIABLES      
*********************************************************************************************************
*/

/* Functions that are called from the External Interrupt routine use these global */
/* variables instead of local variables to avoid stack corruption on CPU's that   */
/* that use overlay memory.  See note in WFEintHandler() function.                */
static UINT8 g_txBuf[3];
static UINT8 g_rxBuf[3];

static UINT8 g_HostIntSaved = 0;

// Keep these as static globals instead of local variables in the Eint Handler.
// If declared as local variables, causes stack corruption in PIC18
static UINT8  g_EintHostIntRegValue;
static UINT8  g_EintHostIntMaskRegValue;
static UINT8  g_EintHostInt;

static BOOL             g_MgmtReadMsgReady;                  /* TRUE if rx mgmt msg to process, else FALSE              */
static volatile BOOL    g_ExIntNeedsServicing;               /* TRUE if external interrupt needs processing, else FALSE */

#if defined(WF_USE_POWER_SAVE_FUNCTIONS)
    static BOOL g_EnablePowerSaveMode = FALSE;
#endif

tRawMoveState RawMoveState;
extern BOOL g_WaitingForMgmtResponse;
BOOL g_DhcpSuccessful = FALSE;
BOOL g_WiFiConnectionChanged = FALSE;
BOOL g_WiFiConnection = FALSE;
BOOL g_dhcpInProgress = FALSE;


extern BOOL g_rxDtim;

/*
*********************************************************************************************************
*                                       LOCAL FUNCTION PROTOTYPES      
*********************************************************************************************************
*/
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

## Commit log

2013-03-04 added all the small boards, renamed Wifi module as RH and LH version
    [BMP085_HIH6130.brd, BMP085_HIH6130.sch, BOM_Base.csv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]
2013-03-08 updated BOM with all prices- As Checked in to BATCH PCB
    [BMP085_HIH6130.brd, BMP085_HIH6130.sch, BOM_Base.csv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]
2013-04-25 Wind speed board and base station rework to rev HW 1.2
    [BOM_STATION_all.xlsx, Base.brd, Base.sch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]
2013-09-24 Revision B.1
    [BOM_STATION_all.xlsx, Base.brd, Base.sch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]
2013-11-12 added fail safe code for WiFi module crash -- send Reset after 10 minutes changed the I2C bit-rate to slowest possible to accommodate long sensor cable changed the UART configuration menu to switch b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
    [Main.c, UARTConfig.c, WunderHttpClient.c]
2013-11-26 Changed to RJ11 connector for Baro_temp_hyg on base board -- Cleaned up some silk screen stuff Added new RJ11 based Baro_Temp_Hyg board layout
    [Base.brd, Base.sch, RJ11_Baro_Hyg.brd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]
2013-12-03 Added code to deal with the situation when someone removed the I2C sensors from a running system or the I2C communication otherwise fails midstream. Executes a system wide reset.
    Added code to execute a system wide reset in case the WiFi connection can not be established within 10 minutes, or the WiFi adapter crashed.
    [BMP085_Baro.c, HIH_6130.c, Main.c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]
2013-12-26 added SILabs Hygrometer board Added frames to the schematics
    [BMP085_HIH6130.brd, BOM_STATION_all.xlsx, Base.brd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]
2014-01-28 Added support for Silabs 7021 hygrometer- Changed and added LED blink and status indication Added metric local web display. Added Density Altitude to local web display
2014-03-04 Changed commands to USB UART to set device into configuration mode.
2014-03-04 Added multiple new boards - H-pwrdist- Insp_Wind_enc, 5040 etc..
    [BMP085_HIH6130.sch, Base.brd, Base.sch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]
2015-01-08 doubled the timeout time that casues a WiFi assertion from .5s to 1 S. This is only used when the stack is used in debug trace mode
2015-01-08 turned off stack debug trace mode
2015-01-08 Added connections to CWOP and WOW servers. Changed Wind averaging to accomodate CWOP report time frames
2015-06-30 added PCB for BOSH PMP180 revised WE28 schemaitc with added text
    [BOM_STATION_all.xlsx, RJ11BMP180_SiHyg.brd, RJ11BMP180_SiHyg.sch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]
2015-10-19 added/changed some comments on schematic regarding Wind dir build options
    [Base.brd, Base.sch, RJ11_BoshBaro_SiHyg.brd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]
2016-02-11 Modified the RF carrier slightly with longer pads for easier soldering.
    [LH_ MRF24_Module.brd, LH_ MRF24_Module.sch, RH_MRF24_Module.brd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]
2016-02-11 Initialized the RTC clock to all 0's during setup and added date&time to compass.svg This is that in case the NIST connection fails it will display a date of 2000 instead of random dates. Changed the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
    Consolidated the NIST TCIP IP socket buffer with the default one and used it instead.
    [NistTimeClient.c, TCPIP MRF24W.h, Wunder_cfg.h]
2016-02-18 Added code so that the system waits for completion of a DHCP operation before anything else accesses the LAN. This is in response to an issue where the networked was accesses with an old, statically 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
    Reverted the NIST state machine back to start up immediately and not have an initial delay to let DHCP complete, since now the system is blocking until DHCP is complete if enabled.
    [Main.c, NistTimeClient.c, TCPIP MRF24W.h]
2016-03-02 Updated BOM with Mouser PN's -- Updated Wind-direction DOC and PDF Updated wind dir doc to better reflect the specifications of the new sensor
    [BOM_STATION_all.xlsx]
2016-03-02 Updated to use new MRF24EG module allowing for 802.11g mode communication. Note that most of the changes are in the MPLAB project, enabling the specific mrf24WG version of the files to be compiled. R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
2016-03-02 changed BOM to reflect new MRF24WG module
    [BOM_STATION_all.xlsx]
2016-03-02 moved interrupter wheel .brd into this folder --
    [rotor.brd]
2016-05-17 Modified the rain counting so that each tip of the bucket immediate updates a software counter via interrupt. This allows WX3D software to calculate the instantaneous rain rate. Also change the avera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
2016-12-09 Reverted back to 60 minute summing of rain readings for RainIn parameter. WU specifies RainIn to be the fallen rain in the last 60 minutes, not instant rain rate, not extrapolated rain rate from a sh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
    [Once_per_second.c, Wunder_cfg.h]
2017-04-04 Removed old Soil Moisture if-defed code Added raw adc10-15 vars to send ADC raw values to http for soil moisture and other use of analog inputs changed html files accordingly by adding a new adcs.htm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
2017-04-04 Changed the default ADC scale factor for adc0-2 to 15V to correspond with the default HW configuration added commentary .c file for soil moisture linearization for Vegetronix VH400 -- code is not inc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
2017-04-10 Reverted the MAC broadcast interval back to 5 seconds from 50. Added new compass.svg file for soil moisture optional build to not display the compass rose, but instead Soil M readings Fixed ADC scali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
    [WX_WUNDER_BRD_MRF24W.h]
2017-07-28 Added output option for RF APRS for use with the Nano APRS modem hardware Added spec sheet for WE28 Wind direction sensor Fixed some spelling mistakes.
    [CWOP_Client.c, HW_initialize.c, Main.c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]
2017-09-18 Added some info on sink and drive currents as well as RPM to MPH conversion factors
2018-10-29 Added APRS radio power control, Added solar to items reported fixed a few compiler warnings
    [APP_cfg.c, CWOP_Client.c, CustomHTTPApp.c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]
2019-02-08 additions and changes for APRS based reporting with telemetry reports for battery voltage and snow height & range. Power control for radio.
